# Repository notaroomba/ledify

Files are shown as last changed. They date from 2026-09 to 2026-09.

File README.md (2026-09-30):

<h1 align="center">
  <br>
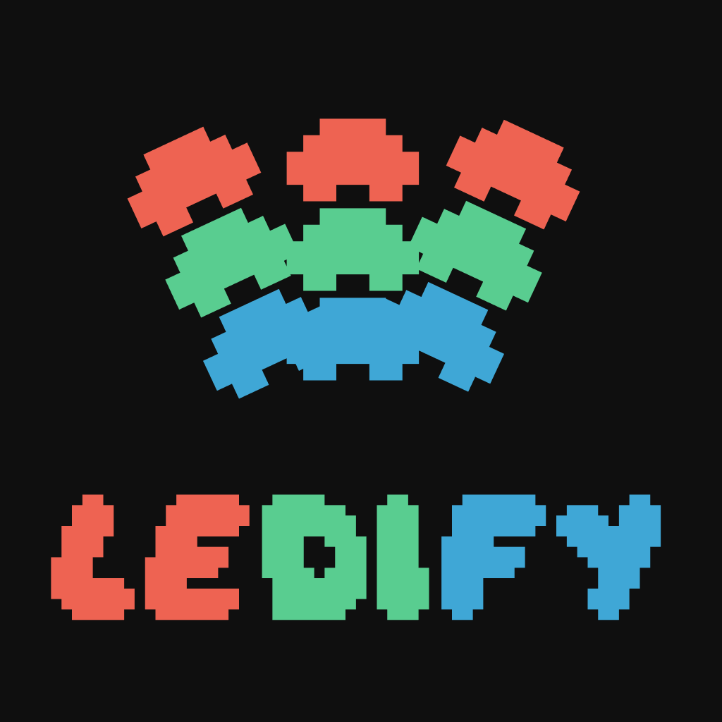
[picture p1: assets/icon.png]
Ledify
  
</h1>

<h4 align="center">
A super small addressable LED controller with USB-C PD up to 100W, a switchable 5V/12V output and Bluetooth!
</h4>

<div align="center">





</div>

<p align="center">
  <a href="#key-features">Key Features</a> •
  <a href="#pcb">PCB</a> •
  <a href="#firmware">Firmware</a> •
  <a href="#credits">Credits</a> •
  <a href="#license">License</a>
</p>

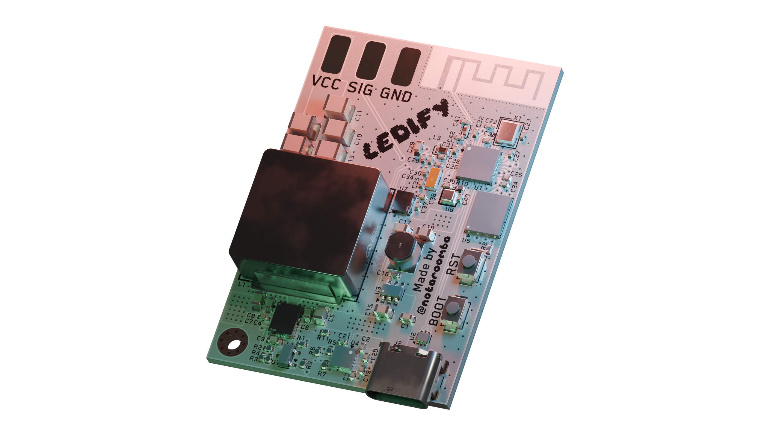
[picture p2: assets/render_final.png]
Ledify Render


## Key Features

- **ESP32-C6** microcontroller with Wi-Fi 6 and Bluetooth LE
- **16MB flash** (W25Q128JVP)
- **USB-C PD** up to 100W with the FUSB302B
- **Switchable 5V/12V LED output** from a 10A buck converter (LM61495), selected in software
- **Addressable LED pads** (VCC / SIG / GND) for WS2812B, WS2811 and WS2815 strips
- **IMU and Barometer** - BMI323 (6-axis) and BMP581 pressure sensor
- **Ambient light sensor** (OPT4001) for automatic brightness
- **I2S microphone** (ICS-43434) for sound-reactive effects
- **PCB trace antenna** with an impedance matching network
- **3.3V buck converter** (AP63203) for the logic side
- **ESD protection** on the USB data lines
- **Reset and boot buttons** and a mounting hole
- **4-layer PCB** design with optimized RF layout and routing

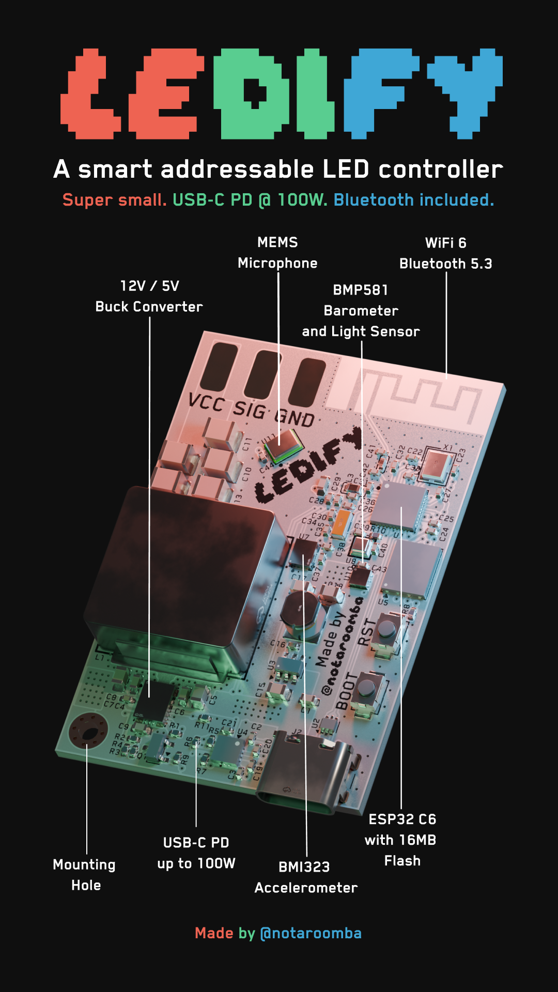
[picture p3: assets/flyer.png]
Ledify Flyer


## PCB

Designed in KiCad with attention to RF design and high current power delivery. The board is 4 layers with a solid ground plane under the ESP32, the flash and the antenna feed, and the LED buck follows the layout in the LM61495 datasheet.

### Schematic

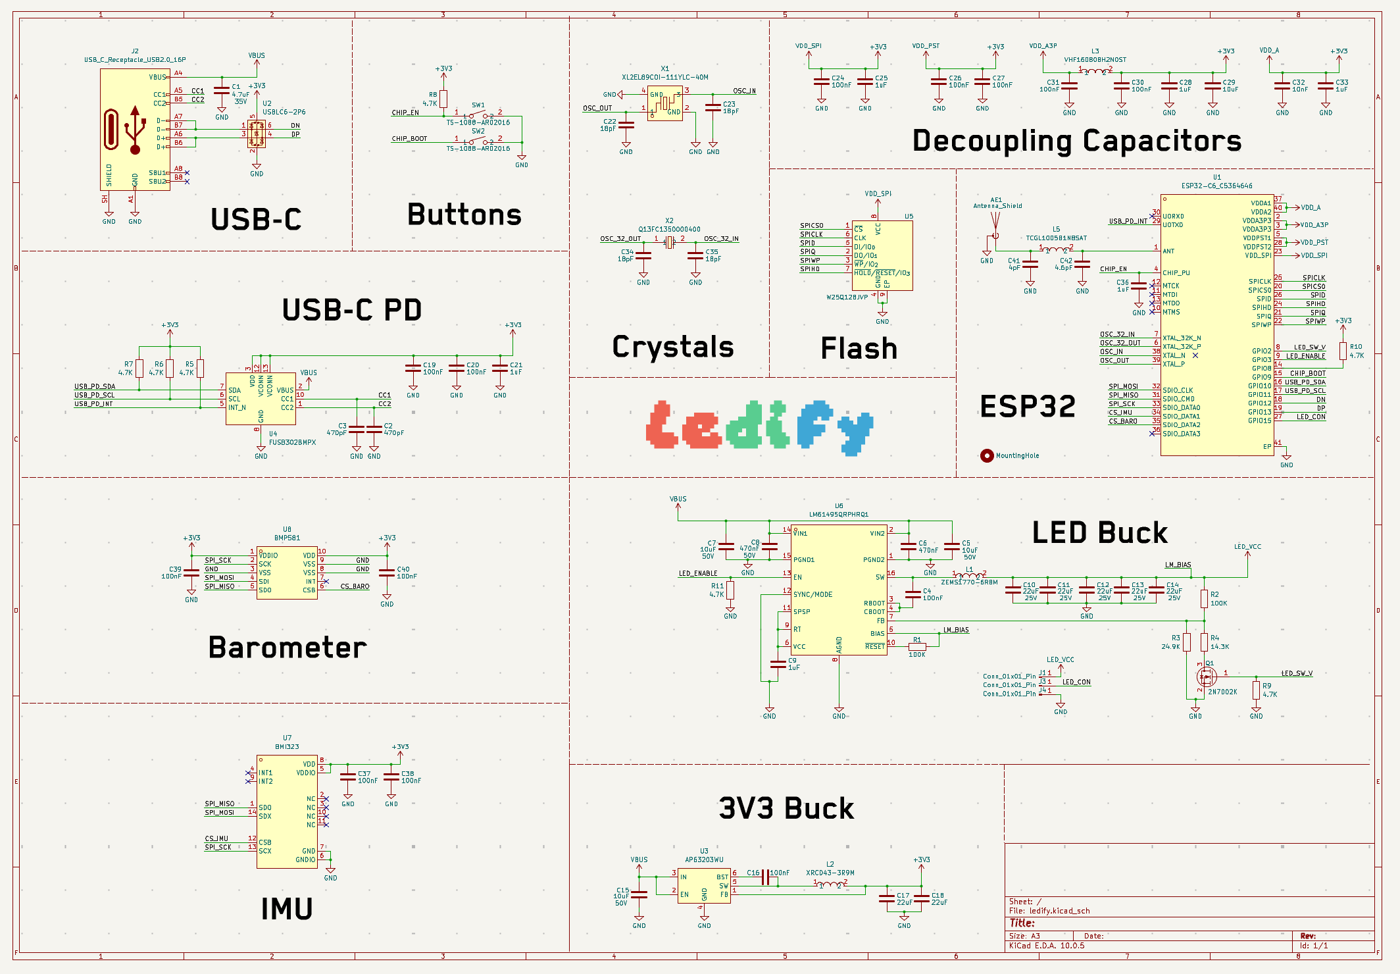
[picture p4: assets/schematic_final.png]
Schematic


### Layout

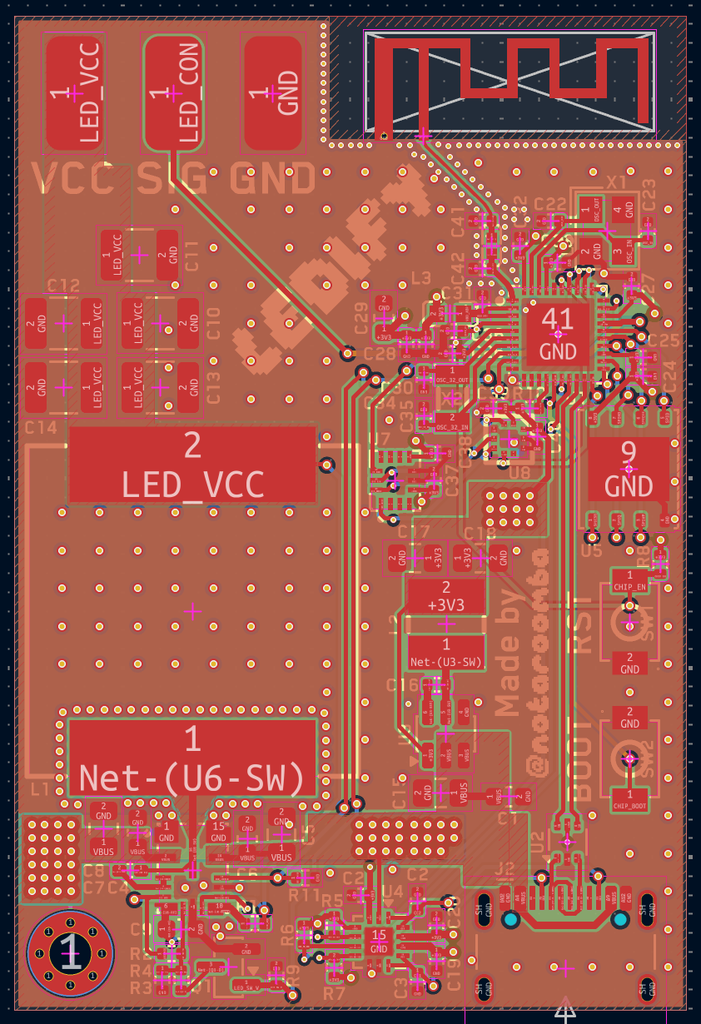
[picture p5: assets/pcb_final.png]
PCB Layout


### Pinout

| GPIO | Net | Function |
| ---- | --- | --- |
| 2 | LED_SW_V | LED voltage select (low = 5V, high = 12V) |
| 3 | LED_ENABLE | LED buck enable |
| 5 | LED_CON | LED data (SIG pad) |
| 6 | MIC_OUT | Microphone I2S data |
| 22 | MIC_CS | Microphone I2S word select |
| 23 | MIC_SCK | Microphone I2S bit clock |
| 10 | I2C_SDA | I2C data (FUSB302B, OPT4001) |
| 11 | I2C_SCL | I2C clock (FUSB302B, OPT4001) |
| 16 | USB_PD_INT | FUSB302B interrupt |
| 18 | SPI_MISO | Sensor SPI |
| 19 | SPI_MOSI | Sensor SPI |
| 20 | SPI_SCK | Sensor SPI |
| 21 | CS_IMU | BMI323 chip select |
| 7 | CS_BARO | BMP581 chip select |
| 12 | DN | USB D- |
| 13 | DP | USB D+ |
| 9 | CHIP_BOOT  | Boot button |
| 8 | - | Strapping pin, pulled up to 3V3 |

### JLCPCB Quote

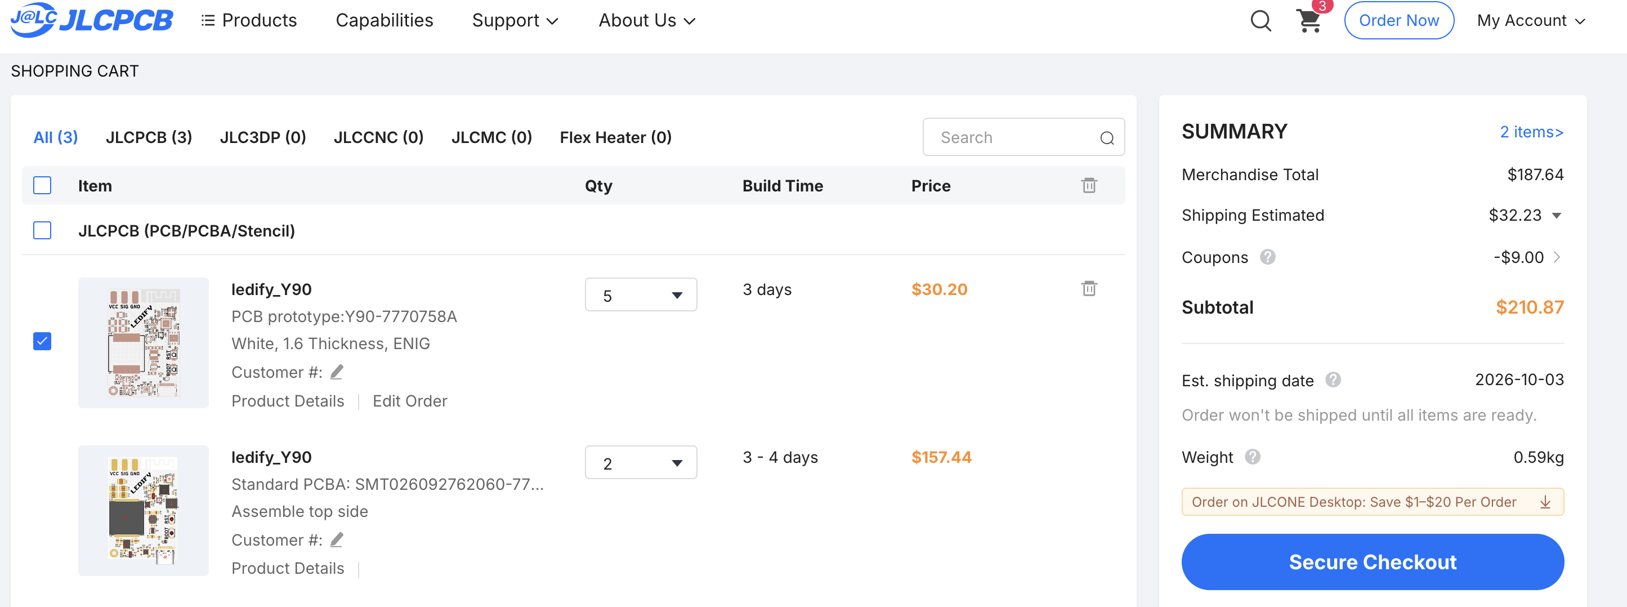
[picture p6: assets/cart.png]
JLCPCB Quote


## Firmware

The boilerplate in [`firmware/main.py`](firmware/main.py) is written in MicroPython. It advertises over Bluetooth as `Ledify` with the Nordic UART service, so any BLE UART app (nRF Connect, Bluefruit Connect) can control the strip.

| Command | Action |
| --- | --- |
| `on` | Turns on the LED buck |
| `off` | Clears the strip and turns off the LED buck |
| `rgb R G B` | Fills the strip with a color (0-255 each) |
| `volt 5` | Selects 5V, turns the output off first |
| `volt 12` | Selects 12V, turns the output off first |

The output always boots at 5V and off. Set `NUM_LEDS` and `MAX_LEVEL` at the top of the file for your strip.

### Flashing

1. Flash the [MicroPython ESP32-C6 firmware](https://micropython.org/download/ESP32_GENERIC_C6/) over USB with `esptool`
2. Copy the boilerplate to the board:

```bash
mpremote cp firmware/main.py :main.py
```

3. Press RST and connect to `Ledify` over Bluetooth

To run the parser self-check on your computer:

```bash
python3 firmware/main.py
```

## Credits

This project uses:

- [KiCad](https://www.kicad.org/)
- [Blender](https://www.blender.org/) for 3D renders
- [MicroPython](https://micropython.org/)

## You may also like...

- [Cyberboard](https://github.com/NotARoomba/cyberboard) – A Raspberry Pi Pico-sized STM32 development board
- [CyberCard](https://github.com/NotARoomba/CyberCard) – A Cyberpunk themed NFC hacker card
- [Ember](https://github.com/NotARoomba/ember) – USB-C PD Powered Hotplate
- [Trace](https://github.com/NotARoomba/trace) – An ruler for engineers
- [Athena](https://github.com/NotARoomba/athena) – A flight controlelr with a triple MCU architecture

## License

MIT

---

> [notaroomba.dev](https://notaroomba.dev) &nbsp;&middot;&nbsp;
> GitHub [@NotARoomba](https://github.com/NotARoomba) &nbsp;&middot;&nbsp;

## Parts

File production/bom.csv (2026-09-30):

Designator | Footprint | Quantity | Value | LCSC Part #
AE1 | Texas_SWRA117D_2.4GHz_Right | 1 | Antenna_Shield
C1 | 0603 | 1 | 4.7uF 35V | C307467
C10, C11, C12, C13, C14 | 1210 | 5 | 22uF 25V | C309062
C15, C5, C7 | 0805 | 3 | 10uF 50V | C440198
C16, C19, C20, C24, C26, C27, C30, C31, C37, C38, C39, C4, C40, C43, C44 | 0402 | 15 | 100nF
C17, C18 | 0805 | 2 | 22uF
C2, C3 | 0402 | 2 | 470pF | C76971
C21, C25, C28, C33, C36 | 0402 | 5 | 1uF
C22, C23, C34, C35 | 0402 | 4 | 18pF | C1549
C29 | 0603 | 1 | 10uF
C32 | 0402 | 1 | 10nF
C41 | 0402 | 1 | 4pF | C541337
C42 | 0402 | 1 | 4.6pF | C1855288
C6, C8 | 0603 | 2 | 470nF 50V | C77572
C9 | 0603 | 1 | 1uF
J1, J3, J4 | SolderWirePad_1x01_SMD_3x6mm | 3 | Conn_01x01_Pin
J2 | USB_C_Receptacle_HCTL_HC-TYPE-C-16P-01A | 1 | USB_C_Receptacle_USB2.0_16P | C2894897
L1 | IND-SMD_L17.5-W17.5_SLO1770H | 1 | ZEMS1770-6R8M | C41438687
L2 | IND-SMD_L4.0-W3.2_XRCD43 | 1 | XRCD43-3R9M | C5289397
L3 | L0603 | 1 | VHF160808H2N0ST | C395081
L5 | L0402 | 1 | TCGL1005B1N8SAT | C52109814
Q1 | SOT-23 | 1 | 2N7002K
R1, R2 | 0402 | 2 | 100K
R10, R11, R5, R6, R7, R8, R9 | 0402 | 7 | 4.7K
R3 | 0402 | 1 | 24.9K
R4 | 0402 | 1 | 14.3K | C25855
SW1, SW2 | SW-SMD_L3.9-W3.0-P4.45 | 2 | TS-1088-AR02016 | C720477
U1 | QFN-40_L5.0-W5.0-P0.40-TL-EP3.3 | 1 | ESP32-C6_C5364646 | C5364646
U10 | USON-6_L2.0-W2.0-P0.65-BL-EP | 1 | OPT4001DNPRQ1 | C20199903
U11 | MIC-SMD_6P-L3.5-W2.7-P0.90-BL | 1 | ICS-43434_C5656610 | C5656610
U2 | SOT-666 | 1 | USBLC6-2P6
U3 | TSOT-23-6 | 1 | AP63203WU | C780769
U4 | WQFN-14-1EP_2.5x2.5mm_P0.5mm_EP1.45x1.45mm | 1 | FUSB302BMPX | C132291
U5 | WSON-8-1EP_6x5mm_P1.27mm_EP3.4x4.3mm | 1 | W25Q128JVP | C2441427
U6 | VQFN-16_L4.5-W3.5-P0.50-TL_TI_RPH | 1 | LM61495QRPHRQ1 | C3188410
U7 | LGA-14_L3.0-W2.5-P0.50-TL_QMI8658A | 1 | BMI323 | C5368700
U8 | LGA-10_L2.0-W2.0-P0.50-TL_BMP581 | 1 | BMP581 | C5362283
X1 | CRYSTAL-SMD_4P-L3.2-W2.5-BL | 1 | XL2EL89COI-111YLC-40M | C18214314
X2 | FC-135R_L3.2-W1.5 | 1 | Q13FC1350000400 | C32346

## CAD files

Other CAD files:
blender/ledify.blend

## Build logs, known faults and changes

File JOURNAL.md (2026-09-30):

# Sep 5, 2026

So I'm doing a thing where I'm trying to make a simple led controller that works with USB-C PD and yea. I want this to be able to power either 12V or 5V LEDs depending on a switch in software and ya. I got this so far as I'm using the FUSB302BMPX for USB-C PD negotiation and yea. I still have to choose my buck converters.

Finished big buck and also small buck and learned about n channel and p channel mosfets.
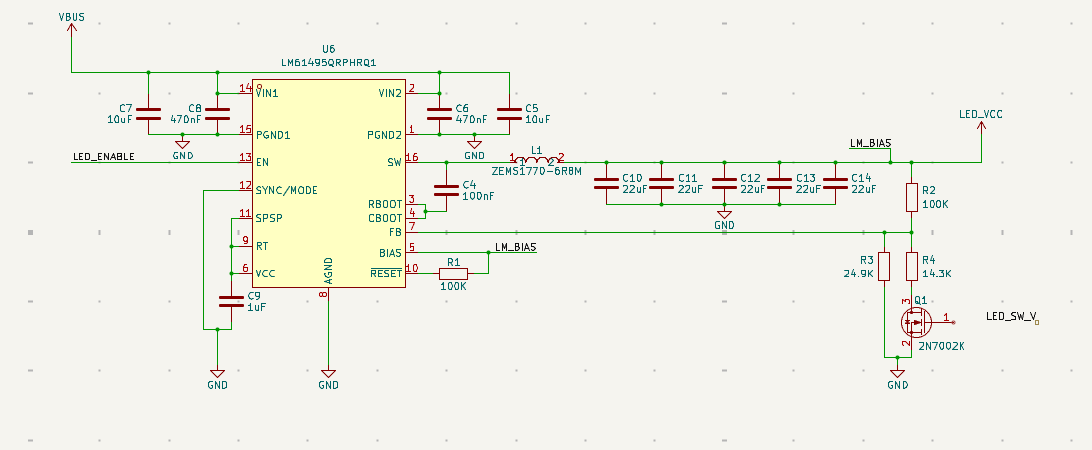
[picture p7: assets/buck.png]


**Total time spent: 6 hours**

# Sep 12, 2026

got basically everything done except the esp32 itself

so I have the usb c going into the FUSB302 for the PD stuff over i2c and then a USBLC6 for esd on the data lines. then theres the small buck (AP63203) that makes the 3V3 for the esp and the big buck with the HUGE inductor for the leds and yea I have the mosfet thing on the feedback so I can switch 5V or 12V from software

also added the crystal and all the decoupling caps for the esp, theres like a million power pins on the c6 (VDDA, VDDA3P3, VDDPST, VDD_SPI) so I put a ferrite on the analog one and caps on all of them like the datasheet says

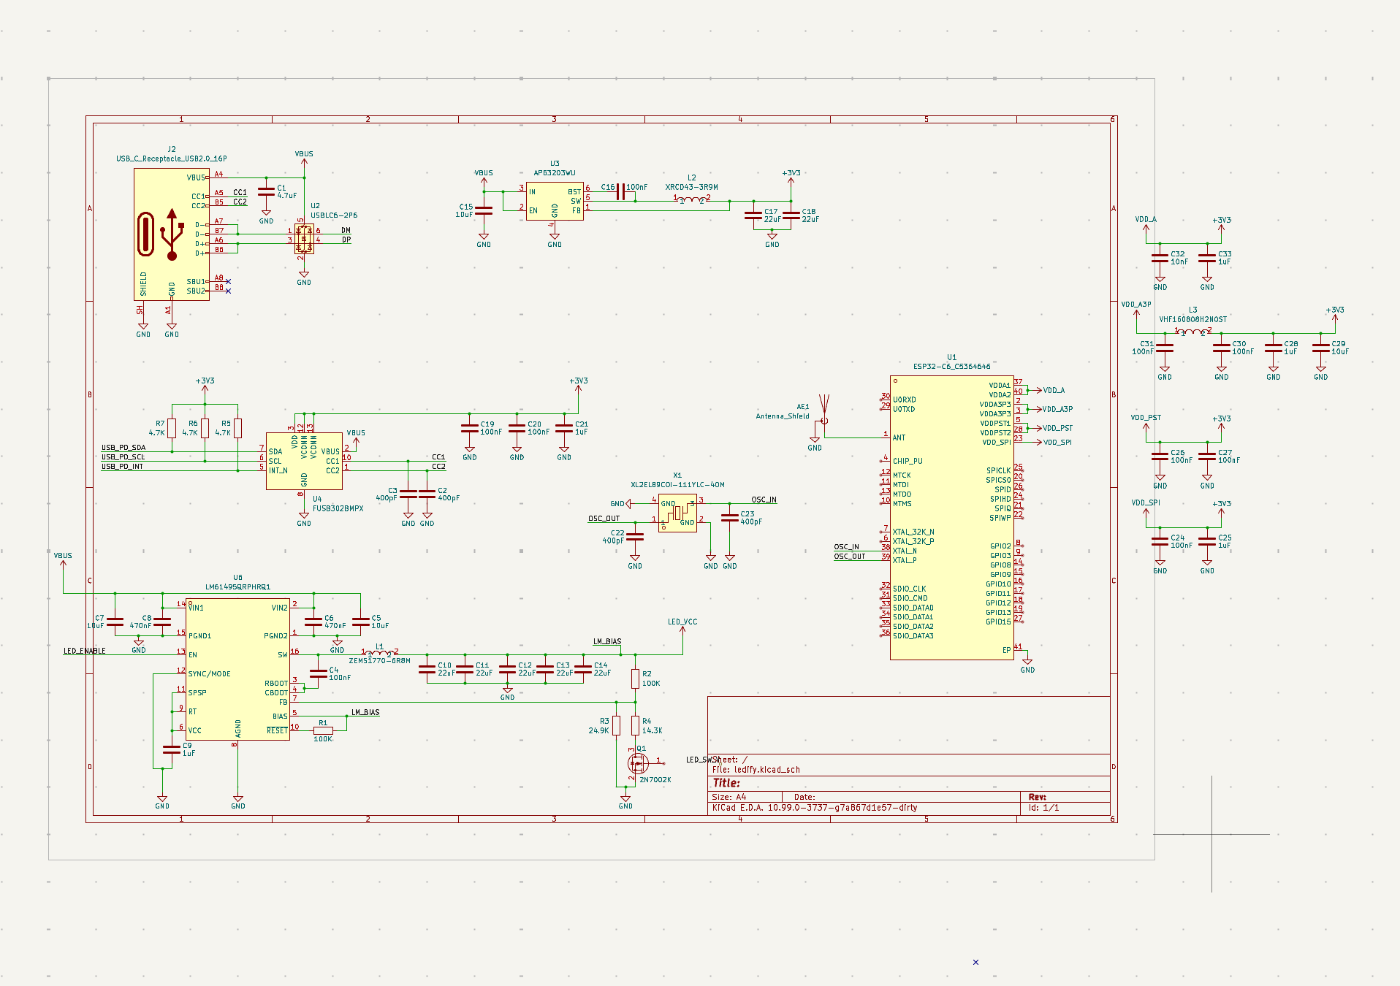
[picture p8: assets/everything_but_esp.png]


now I just have to figure out the esp pinout because I have no idea what goes where lol

**Total time spent: 7 hours**

# Sep 13, 2026

ookay so I've been working on this on and off whenever I had time and I finally got around to finishing the schematic

the thing was I didn't know the esp32 pinout at all so I went through the datasheet and looked at some example schematics that other people made to get an idea of what goes where

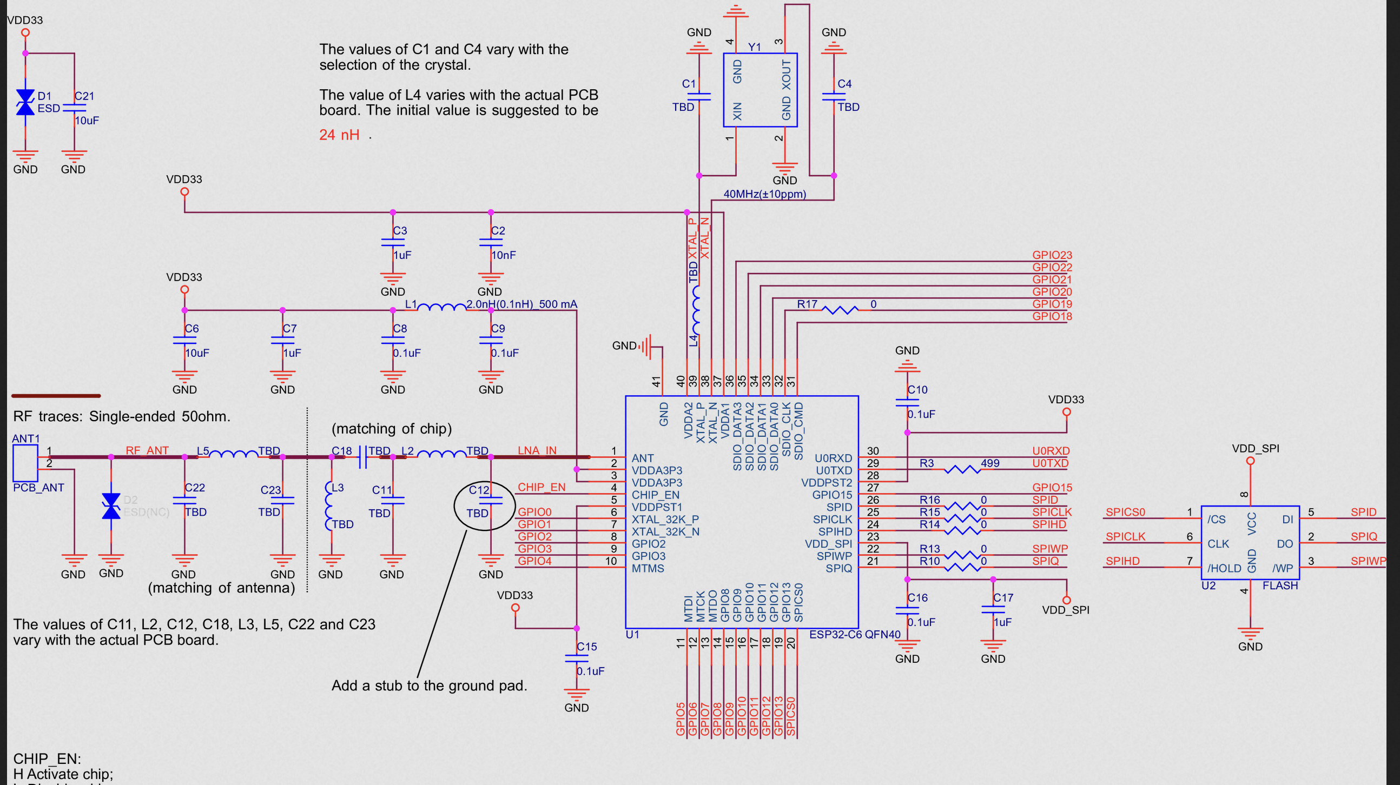
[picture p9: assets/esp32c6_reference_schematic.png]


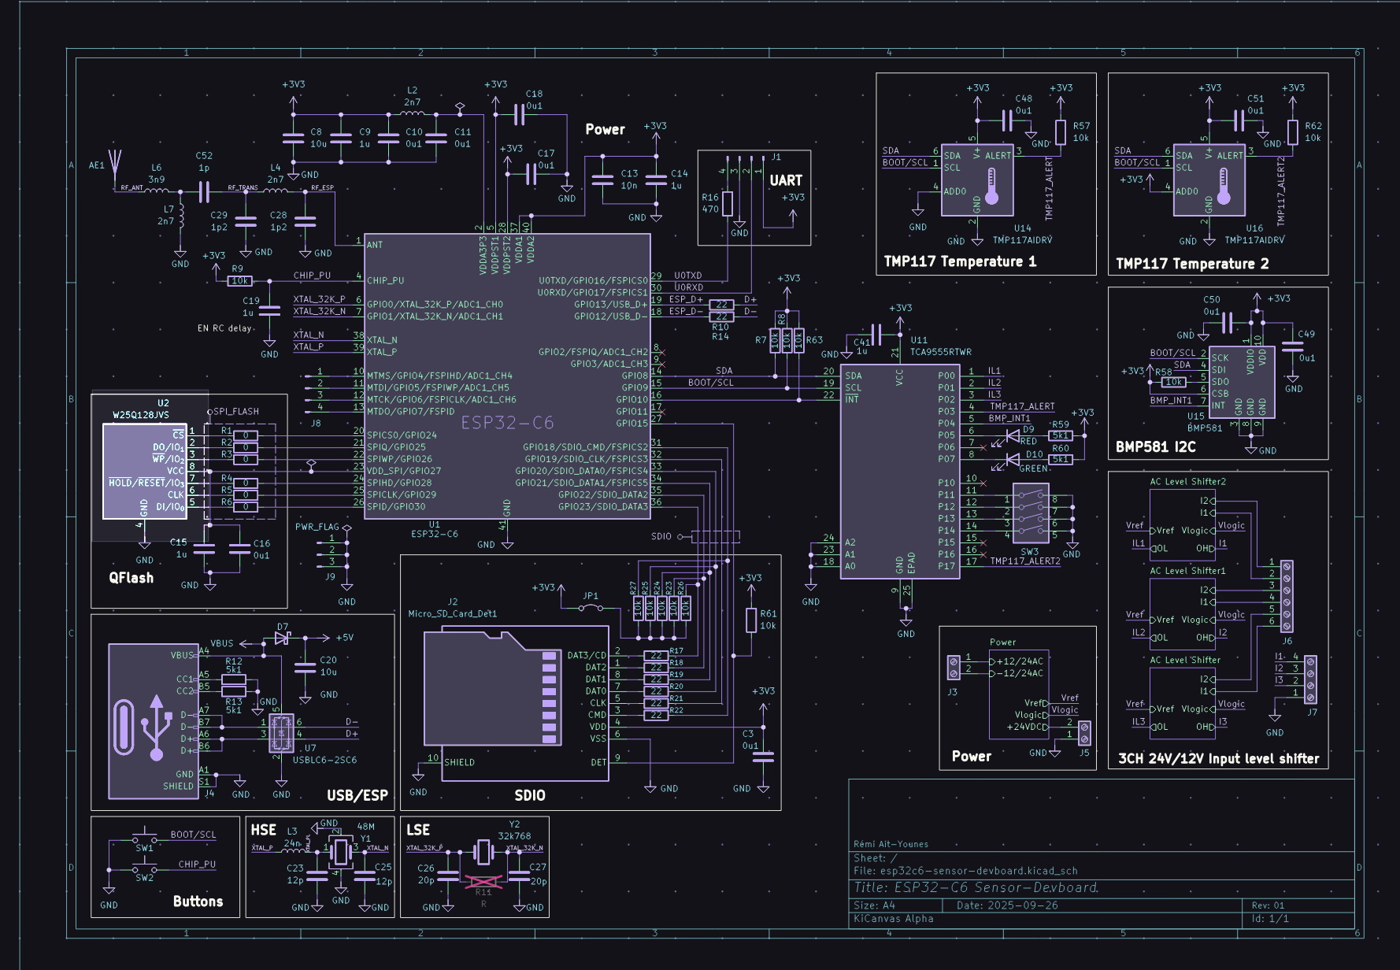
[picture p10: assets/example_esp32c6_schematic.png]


and thats when I found out that on the esp32 literally ANY gpio can be spi or i2c because of the gpio matrix (with some regulations lol) so like you cant use 24-30 because thats the flash on the 40 pin version and 12/13 are usb and 8/9/15 are strapping pins so nothing can pull them at boot. also there are no input only pins on the c6 unlike the og esp32 so that made it easier and yea

**Total time spent: 6 hours**

# Sep 19, 2026

after that I had to go back and look at the datasheet for the big buck again because I wanted to make sure the 5V/12V thing actually worked. basically theres a voltage divider on the feedback pin and the 2N7002K puts another resistor in parallel with the bottom one so off = 5V and on = 12V

but then I realized that when the esp is booting the gpio floats so the mosfet could randomly turn on and send 12V to a 5V strip and kill it so I decided to put a pull down resistor on the gate so it defaults to 5V

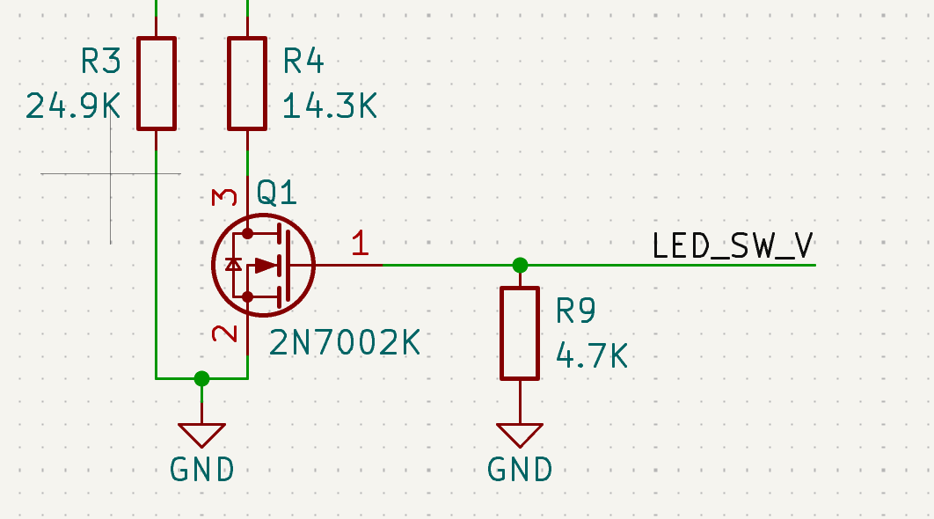
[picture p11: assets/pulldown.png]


also had to double check all the caps because VBUS can go up to 20V with PD so the input caps need to be rated for way more than what I had

**Total time spent: 6 hours**

# Sep 20, 2026

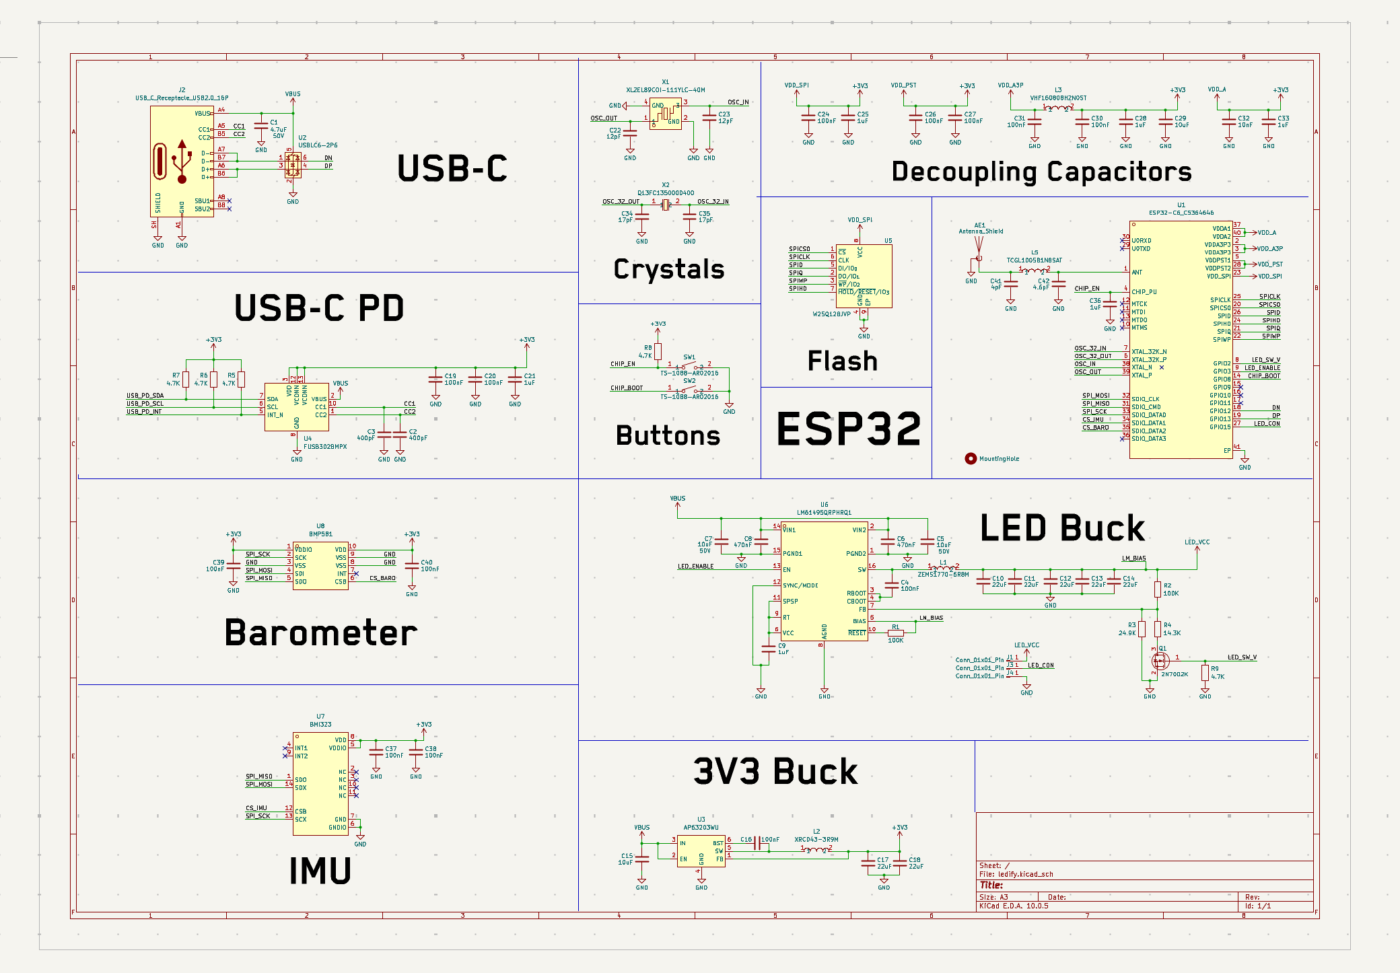
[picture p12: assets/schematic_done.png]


schematic done so now its time for the pcb!!!

I had some trouble laying it out at first because the led inductor is HUGE (17.5mm) and I didn't know where to put it next to the esp and the flash. turns out its fine to have it next to the flash as long as the switch node is pointing away and the ground plane is solid so I just rotated it

the bigger problem was the antenna, I originally had it in the top left with the led pads and the crystal right next to it. so I moved the antenna to the top right corner against both edges and the led pads to the other side and the crystal below the esp

after a bit of moving stuff around I finally decided on a general layout and grouped everything (usb, small buck, big buck, esp + flash) and started routing

**Total time spent: 5 hours**

# Sep 26, 2026

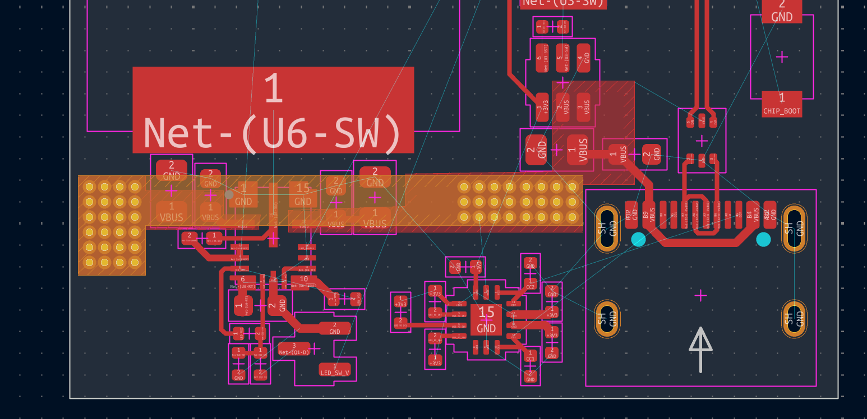
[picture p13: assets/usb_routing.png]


I routed the usb stuff first since that was the easiest and then went through the rest

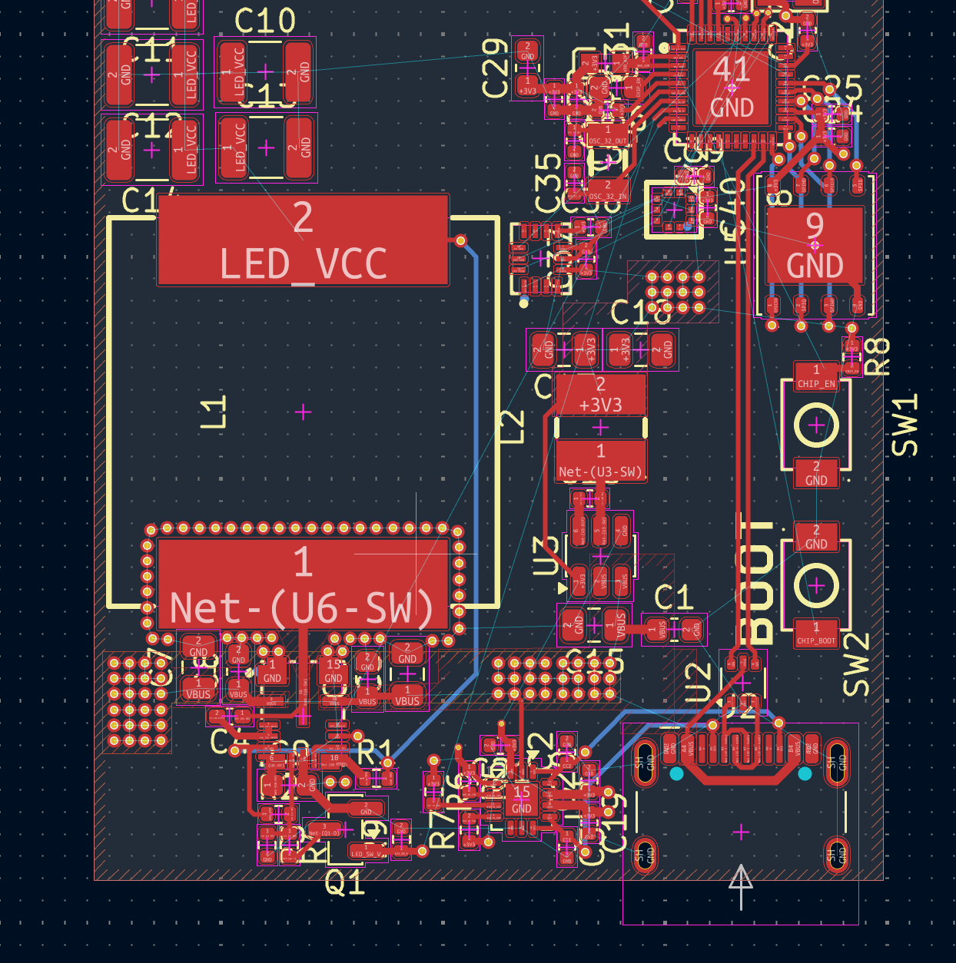
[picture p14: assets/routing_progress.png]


then it was time for the antenna and heres where I had to learn a bit more about rf theory. I'm using a meander pcb antenna and apparently the ground plane is literally part of the antenna so it has to be at a specific distance from it. I originally had a massive keepout below it with the feed trace running through empty board which is bad because the trace has no ground reference so its basically another antenna lol

so I pulled the ground pour up so its right under the antenna pads and made the feed trace super short with vias on both sides and yea

I also had to make a matching circuit for the first time!! the esp is like 35 + 10j ohms and the antenna wants 50 + 0j so I had to calculate the pi network to get it there and it was the first time actually doing the smith chart stuff for real instead of just copying values

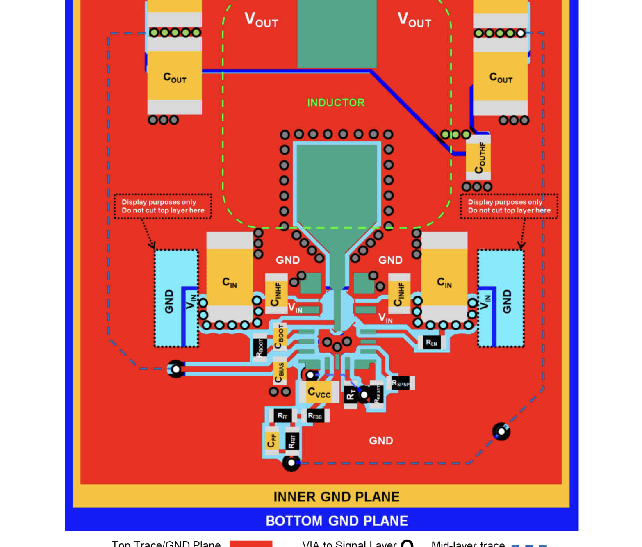
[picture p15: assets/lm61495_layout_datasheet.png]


for the big buck I followed the layout in the datasheet and kept the input caps right at the pins since thats the hot loop. I was also wondering if I should mirror the LED_VCC pour on the bottom with vias for the current but it would cut a hole in the ground plane so I left the ground plane alone

and after around 7 hours of routing today its DONE

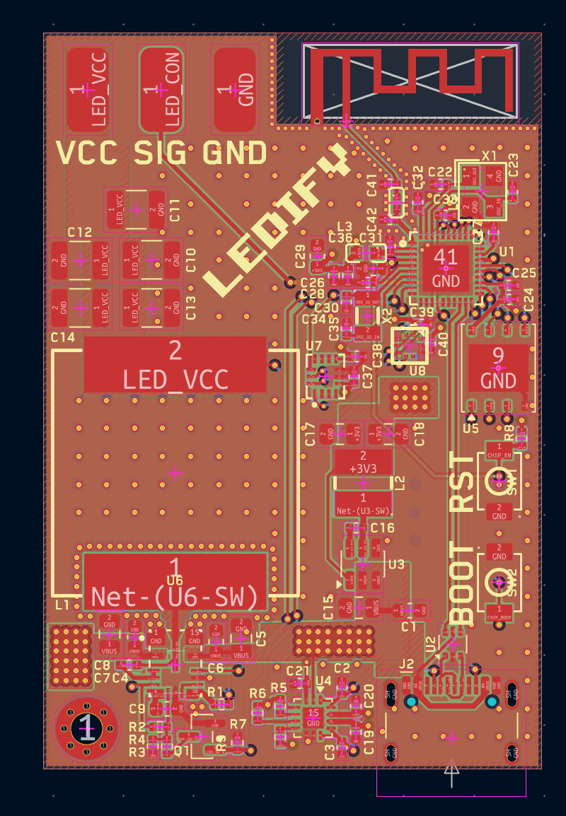
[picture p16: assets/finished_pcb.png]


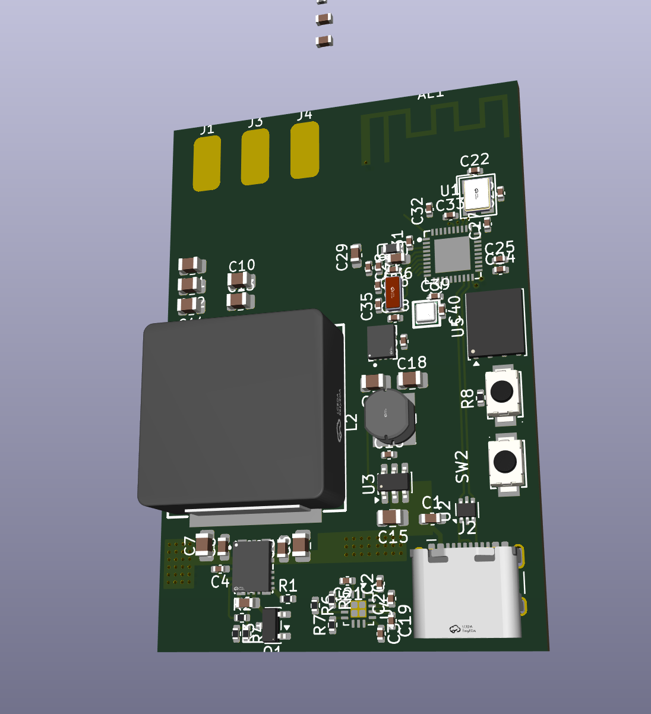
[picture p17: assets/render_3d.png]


**Total time spent: 8 hours**

# Sep 27, 2026

I then did a think with LCSC and JLCPCB and got the final quote on it, I had to bom match because of the 22uF caps adn they had to be rated for 25V because yea usb goes up to 20v


In total it went up to 210 usd ish with shipping and assembly so I think that this is good.

**Total time spent: 2.5 hours**

# Sep 28, 2026

ookay so with the pcb done I started on the blender render yesterday and yea

I exported the board as a pcb3d and imported it into blender and then set up the camera and a bunch of lights around it

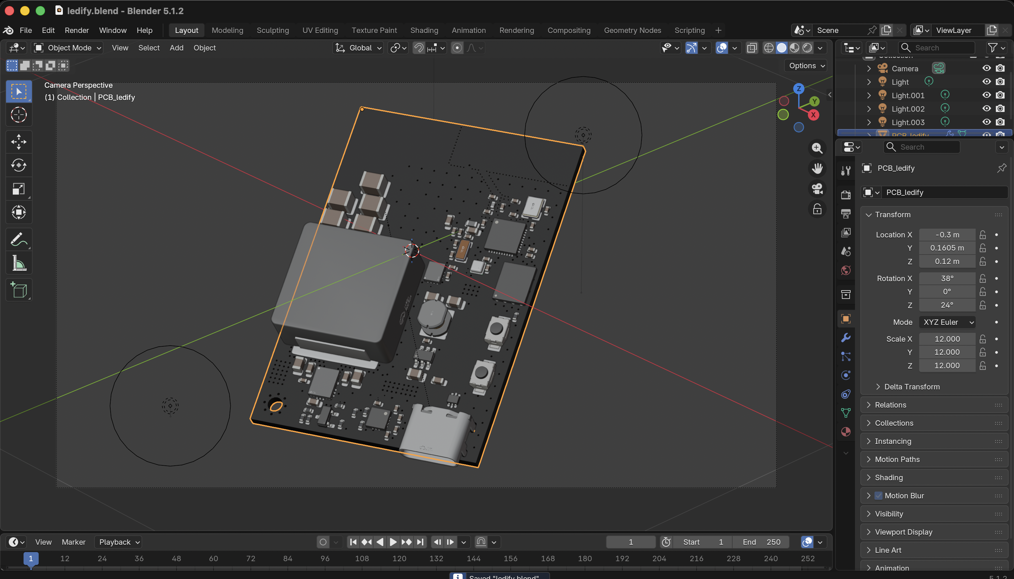
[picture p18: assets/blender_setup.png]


the first renders looked kinda drab so I went through a few versions moving the lights around and giving them colors (red green and blue like an rgb led lol) until it looked good

then today I went on figma and made the logo and the banner and also a flyer that shows everything on the board. I also found a cool pixel font for the name and put it on the silkscreen too

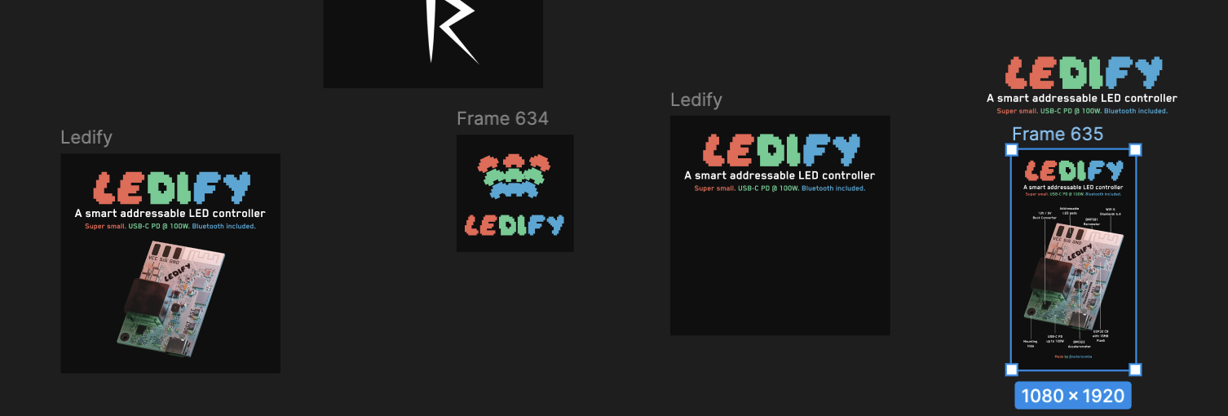
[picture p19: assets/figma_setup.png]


and this is how it ended up!!

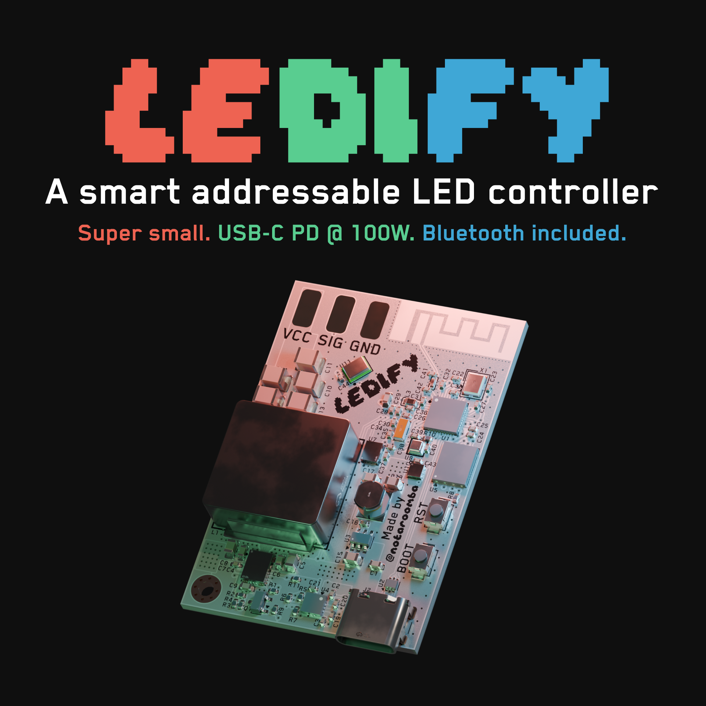
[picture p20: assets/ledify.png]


but then I went back and double checked the schematic and found a few errors lol

the biggest one was that the FUSB302 i2c lines weren't even connected to the esp (they just went to the pull up resistors) so it wouldn't have been able to get anything above 5V which is kinda the whole point of the board. I also had the boot button on GPIO8 instead of GPIO9 so I moved it and put a pull up on GPIO8

then theres the usb esd chip, I had its VBUS pin on VBUS but it can only handle like 6V so with PD at 20V it would have died, so now its on 3V3. I also added a pull down on the led enable so the buck doesn't turn on by itself when the esp is booting

after that I went through all of the LCSC part numbers and some of them didn't match, like the 10uF caps on VBUS were actually 25V instead of 50V and the crystal caps were wrong (the crystals want a 12pF load so the caps have to be 18pF) so I fixed those too





and now the drc has no more errors and the bom matches the schematic so its finally ready to order

**Total time spent: 5 hours**

# Sep 29, 2026

so the board was "done" but I kept thinking of stuff to add lol

first I wanted an ambient light sensor so the leds can dim themselves when the room is dark. I went with the OPT4001 and it's i2c so I just put it on the same bus as the FUSB302 and didn't have to use any more pins. the only space left was next to the 3V3 buck so I put it on the output side away from the inductor. when I added it I accidentally ran some tracks straight through a group of 3V3 vias and shorted CHIP_EN and MISO to 3V3 so I had to fix that

then I looked at the return paths around the esp32 because I thought it was interesting and it turns out I had signal tracks on the inner layers cutting slots in the ground plane right under the chip, and there was only ONE ground via under the esp. so I moved CS_BARO and LED_CON off the planes, changed a few pins around (led data is on GPIO5 now and CS_BARO on GPIO7) and added more ground vias under it

after that I wanted a microphone so the leds can react to sound. I started with an analog one (ZTS6117) but the output is only a few millivolts so the esp adc can't really read it without an op amp and like 10 more parts. so I looked at the MAX9814 and then decided on an i2s mic instead because its one part and the signal is digital so the bucks can't mess with it
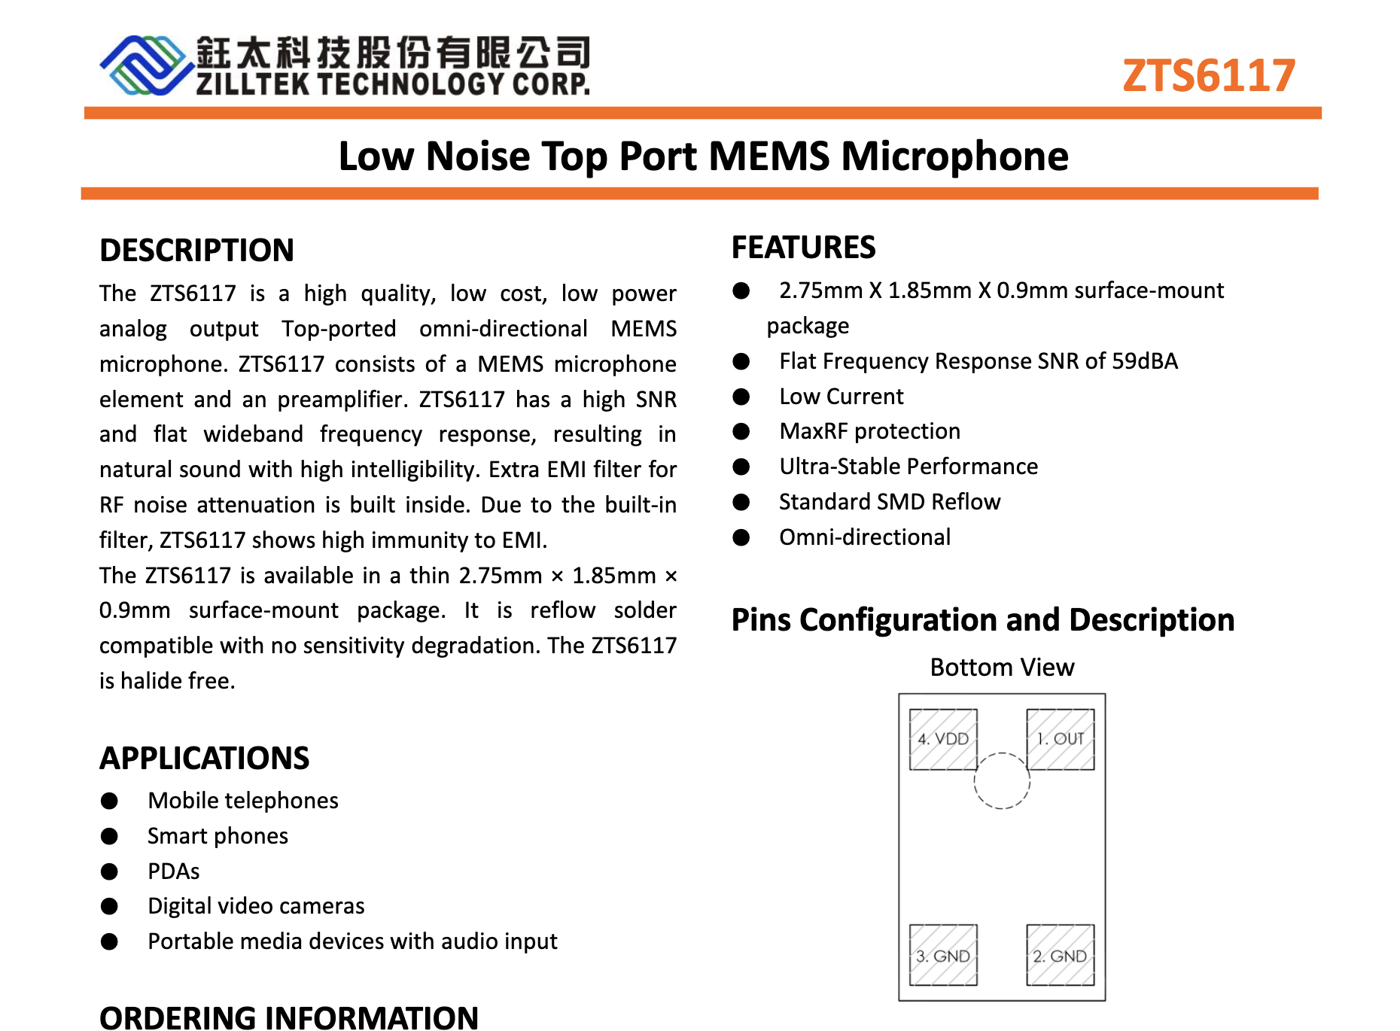
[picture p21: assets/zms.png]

I also tied SYNC/MODE on the big buck to 3V3 so it always switches at the same frequency and doesn't make the caps hum next to the mic

**Total time spent: 4 hours**

# Sep 30, 2026

the i2s mic I picked (MSM261S4030H0R) was out of stock on LCSC so I spent a while looking for another one. apparently top port i2s mics basically don't exist, almost all of them have the hole on the bottom, so I went with the ICS-43434 which is a bit smaller and listens through a hole in the pcb

the footprint had the sound hole as a plated hole with no copper around it which jlc can't make so I changed it to a 0.5mm non plated hole

I also double checked the antenna again. the feed trace is the 50 ohm width for the JLC04161H-3313 stackup and nothing is inside the keepout on any layer so I just have to remember to pick that stackup when I order

then I fixed a 0.1mm track I missed, exported the production files again and redid the renders with the new parts



with the extra sensors the pcba is around 300 usd now for 2 assembled boards, I looked at how much it would be to assemble them myself and its way cheaper per board but the esp32 is 0.4mm pitch and there are 3 LGA sensors so I'm going with pcba for this one

**Total time spent: 2.5 hours**

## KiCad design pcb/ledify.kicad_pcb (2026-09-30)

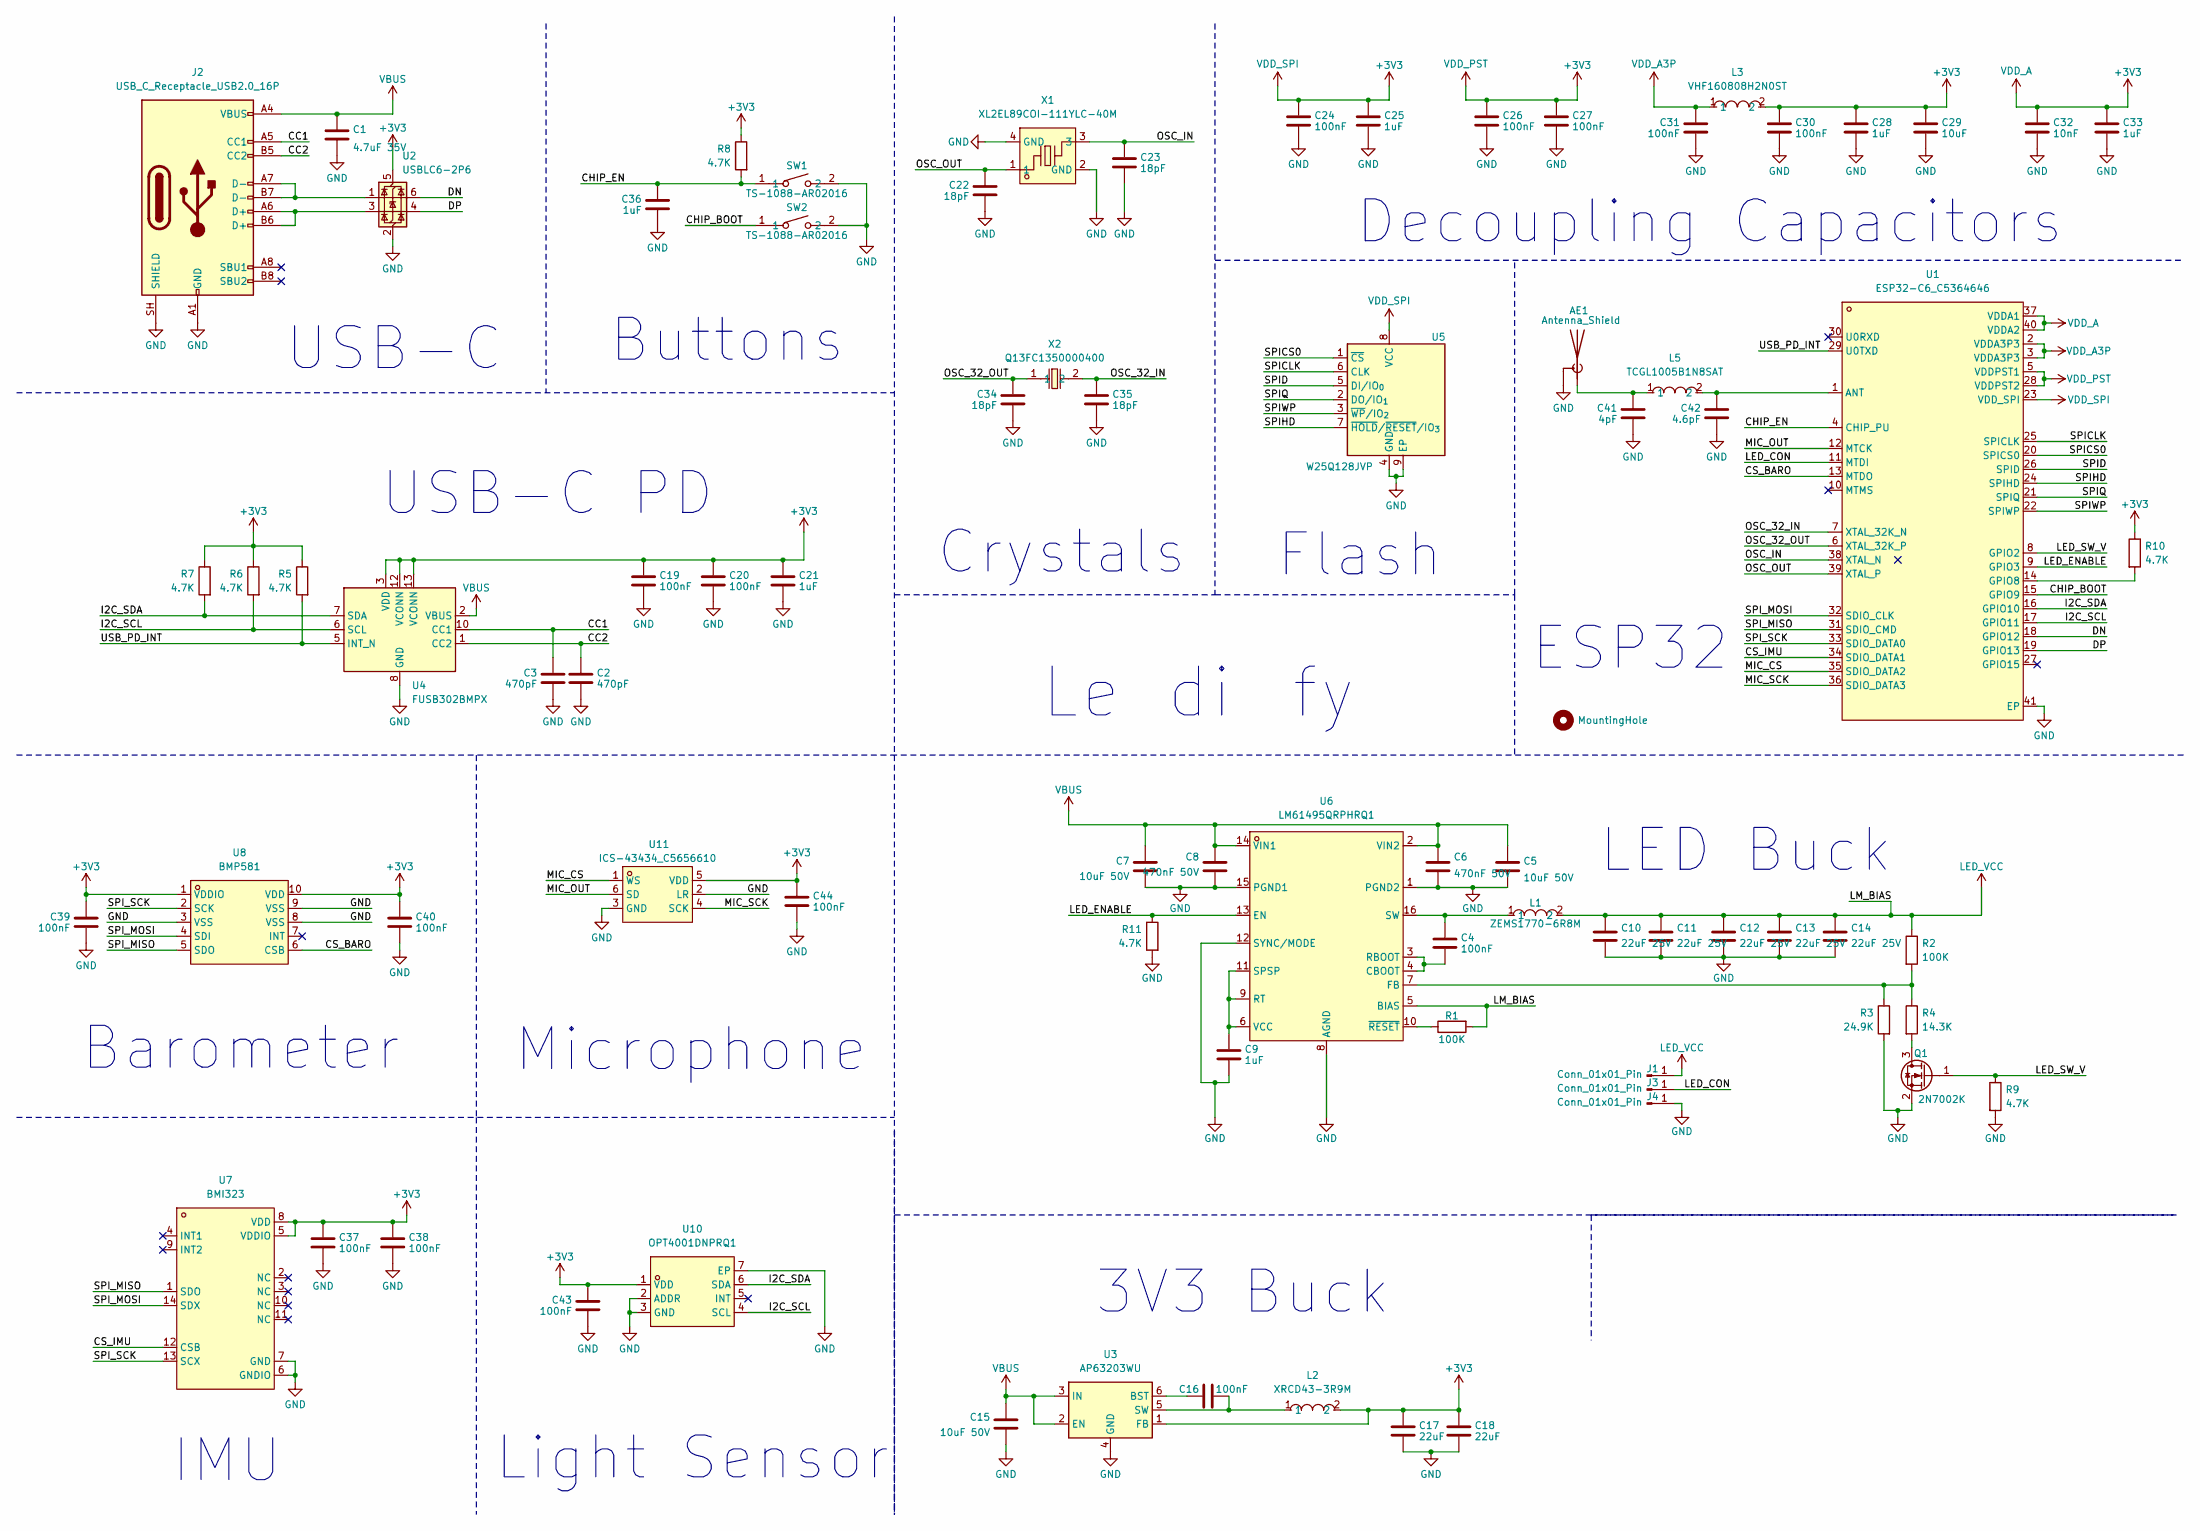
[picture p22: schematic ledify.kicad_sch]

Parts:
AE1: Antenna_Shield; Texas_SWRA117D_2.4GHz_Right
C1: 4.7uF 35V; C_0603_1608Metric; LCSC C307467
C2, C3: 470pF; C_0402_1005Metric; LCSC C76971
C4: 100nF; C_0402_1005Metric_Pad0.74x0.62mm_HandSolder
C5, C7, C15: 10uF 50V; C_0805_2012Metric; LCSC C440198
C6, C8: 470nF 50V; C_0603_1608Metric; LCSC C77572
C9: 1uF; C_0603_1608Metric
C10, C11, C12, C13, C14: 22uF 25V; C_1210_3225Metric; LCSC C309062
C16, C19, C20, C24, C26, C27, C30, C31, C37, C38, C39, C40, C43, C44: 100nF; C_0402_1005Metric
C17, C18: 22uF; C_0805_2012Metric
C21, C25, C28, C33, C36: 1uF; C_0402_1005Metric
C22, C23, C34, C35: 18pF; C_0402_1005Metric; LCSC C1549
C29: 10uF; C_0603_1608Metric
C32: 10nF; C_0402_1005Metric
C41: 4pF; C_0402_1005Metric; LCSC C541337
C42: 4.6pF; C_0402_1005Metric; LCSC C1855288
H1: MountingHole; MountingHole_2.2mm_M2_Pad_Via
J1, J3, J4: Conn_01x01_Pin; SolderWirePad_1x01_SMD_3x6mm
J2: USB_C_Receptacle_USB2.0_16P; USB_C_Receptacle_HCTL_HC-TYPE-C-16P-01A; LCSC C2894897
L1: ZEMS1770-6R8M; IND-SMD_L17.5-W17.5_SLO1770H; MPN ZEMS1770-6R8M; LCSC Part C41438687
L2: XRCD43-3R9M; IND-SMD_L4.0-W3.2_XRCD43; MPN XRCD43-3R9M; LCSC Part C5289397
L3: VHF160808H2N0ST; L0603; MPN VHF160808H2N0ST; LCSC Part C395081
L5: TCGL1005B1N8SAT; L0402; MPN TCGL1005B1N8SAT; LCSC Part C52109814
Q1: 2N7002K; SOT-23
R1, R2: 100K; R_0402_1005Metric
R3: 24.9K; R_0402_1005Metric
R4: 14.3K; R_0402_1005Metric; LCSC C25855
R5, R6, R7, R8, R9, R10, R11: 4.7K; R_0402_1005Metric
SW1, SW2: TS-1088-AR02016; SW-SMD_L3.9-W3.0-P4.45; MPN TS-1088-AR02016; LCSC Part C720477
U1: ESP32-C6_C5364646; QFN-40_L5.0-W5.0-P0.40-TL-EP3.3; MPN ESP32-C6; LCSC Part C5364646
U2: USBLC6-2P6; SOT-666
U3: AP63203WU; TSOT-23-6; LCSC C780769
U4: FUSB302BMPX; WQFN-14-1EP_2.5x2.5mm_P0.5mm_EP1.45x1.45mm; LCSC C132291
U5: W25Q128JVP; WSON-8-1EP_6x5mm_P1.27mm_EP3.4x4.3mm; LCSC C2441427
U6: LM61495QRPHRQ1; VQFN-16_L4.5-W3.5-P0.50-TL_TI_RPH; MPN LM61495QRPHRQ1; LCSC Part C3188410
U7: BMI323; LGA-14_L3.0-W2.5-P0.50-TL_QMI8658A; MPN BMI323; LCSC Part C5368700
U8: BMP581; LGA-10_L2.0-W2.0-P0.50-TL_BMP581; MPN BMP581; LCSC Part C5362283
U10: OPT4001DNPRQ1; USON-6_L2.0-W2.0-P0.65-BL-EP; MPN OPT4001DNPRQ1; LCSC Part C20199903
U11: ICS-43434_C5656610; MIC-SMD_6P-L3.5-W2.7-P0.90-BL; MPN ICS-43434; LCSC Part C5656610
X1: XL2EL89COI-111YLC-40M; CRYSTAL-SMD_4P-L3.2-W2.5-BL; MPN XL2EL89COI-111YLC-40M; LCSC Part C18214314
X2: Q13FC1350000400; FC-135R_L3.2-W1.5; MPN Q13FC13500004; LCSC Part C32346

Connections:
+3V3: C17.1, C18.1, C19.1, C20.1, C21.1, C24.1, C25.1, C26.1, C27.1, C28.1, C29.1, C30.1, C32.1, C33.1, C37.1, C38.1, C39.1, C40.1, C43.1, C44.1, L2.2, L3.2, R5.1, R6.1, R7.1, R8.1, R10.1, U1.5 (VDDPST1), U1.23 (VDD_SPI), U1.28 (VDDPST2), U1.37 (VDDA1), U1.40 (VDDA2), U2.5 (VBUS), U3.1 (FB), U4.3 (VDD), U4.4 (VDD), U4.12 (VCONN), U4.13 (VCONN), U5.8 (VCC), U7.5 (VDDIO), U7.8 (VDD), U8.1 (VDDIO), U8.10 (VDD), U10.1 (VDD), U11.5 (VDD)
/CC1: C3.1, J2.A5 (CC1), U4.10 (CC1), U4.11 (CC1)
/CC2: C2.1, J2.B5 (CC2), U4.1 (CC2), U4.14 (CC2)
/CHIP_BOOT: SW2.1, U1.15 (GPIO9)
/CHIP_EN: C36.1, R8.2, SW1.1, U1.4 (CHIP_PU)
/CS_BARO: U1.13 (MTDO), U8.6 (CSB)
/CS_IMU: U1.34 (SDIO_DATA1), U7.12 (CSB)
/DN: U1.18 (GPIO12), U2.6 (I/O1)
/DP: U1.19 (GPIO13), U2.4 (I/O2)
/I2C_SCL: R6.2, U1.17 (GPIO11), U4.6 (SCL), U10.4 (SCL)
/I2C_SDA: R7.2, U1.16 (GPIO10), U4.7 (SDA), U10.6 (SDA)
/LED_CON: J3.1 (Pin_1_1), U1.11 (MTDI)
/LED_ENABLE: R11.1, U1.9 (GPIO3), U6.13 (EN)
/LED_SW_V: Q1.1 (G), R9.1, U1.8 (GPIO2)
/MIC_CS: U1.35 (SDIO_DATA2), U11.1 (WS)
/MIC_OUT: U1.12 (MTCK), U11.6 (SD)
/MIC_SCK: U1.36 (SDIO_DATA3), U11.4 (SCK)
/OSC_32_IN: C35.1, U1.7 (XTAL_32K_N), X2.2
/OSC_32_OUT: C34.1, U1.6 (XTAL_32K_P), X2.1
/OSC_IN: C23.1, U1.38 (XTAL_N), X1.3
/OSC_OUT: C22.1, U1.39 (XTAL_P), X1.1
/SPICLK: U1.25 (SPICLK), U5.6 (CLK)
/SPICS0: U1.20 (SPICS0), U5.1 (~CS)
/SPID: U1.26 (SPID), U5.5 (DI/IO_{0})
/SPIHD: U1.24 (SPIHD), U5.7 (~HOLD/~RESET/IO_{3})
/SPIQ: U1.21 (SPIQ), U5.2 (DO/IO_{1})
/SPIWP: U1.22 (SPIWP), U5.3 (~WP/IO_{2})
/SPI_MISO: U1.31 (SDIO_CMD), U7.1 (SDO), U8.5 (SDO)
/SPI_MOSI: U1.32 (SDIO_CLK), U7.14 (SDX), U8.4 (SDI)
/SPI_SCK: U1.33 (SDIO_DATA0), U7.13 (SCX), U8.2 (SCK)
/USB_PD_INT: R5.2, U1.29 (U0TXD), U4.5 (INT_N)
GND: AE1.2 (Shield), C1.2, C2.2, C3.2, C5.2, C6.2, C7.2, C8.2, C9.2, C10.2, C11.2, C12.2, C13.2, C14.2, C15.2, C17.2, C18.2, C19.2, C20.2, C21.2, C22.2, C23.2, C24.2, C25.2, C26.2, C27.2, C28.2, C29.2, C30.2, C31.2, C32.2, C33.2, C34.2, C35.2, C36.2, C37.2, C38.2, C39.2, C40.2, C41.2, C42.2, C43.2, C44.2, J2.A1 (GND), J2.A12 (GND), J2.B1 (GND), J2.B12 (GND), J2.SH (SHIELD), J4.1 (Pin_1_1), Q1.2 (S), R3.2, R9.2, R11.2, SW1.2, SW2.2, U1.41 (EP), U2.2 (GND), U3.4 (GND), U4.8 (GND), U4.9 (GND), U4.15 (GND), U5.4 (GND), U5.9 (EP), U6.1 (PGND2), U6.8 (AGND), U6.12 (SYNC/MODE), U6.15 (PGND1), U7.6 (GNDIO), U7.7 (GND), U8.3 (VSS), U8.8 (VSS), U8.9 (VSS), U10.2 (ADDR), U10.3 (GND), U10.7 (EP), U11.2 (LR), U11.3 (GND), X1.2 (GND), X1.4 (GND)
LED_VCC: C10.1, C11.1, C12.1, C13.1, C14.1, J1.1 (Pin_1_1), L1.2, R1.2, R2.1, U6.5 (BIAS)
unnamed: AE1.1 (A), C41.1, L5.1
unnamed: J2.A6 (D+), J2.B6 (D+), U2.3 (I/O2)
unnamed: J2.A7 (D-), J2.B7 (D-), U2.1 (I/O1)
unnamed: Q1.3 (D), R4.2
unnamed: C42.1, L5.2, U1.1 (ANT)
unnamed: R10.2, U1.14 (GPIO8)
unnamed: C16.1, U3.6 (BST)
unnamed: C16.2, L2.1, U3.5 (SW)
unnamed: C4.2, U6.3 (RBOOT), U6.4 (CBOOT)
unnamed: R2.2, R3.1, R4.1, U6.7 (FB)
unnamed: C9.1, U6.6 (VCC), U6.9 (RT), U6.11 (SPSP)
unnamed: C4.1, L1.1, U6.16 (SW)
unnamed: R1.1, U6.10 (~RESET)
VBUS: C1.1, C5.1, C6.1, C7.1, C8.1, C15.1, J2.A4 (VBUS), J2.A9 (VBUS), J2.B4 (VBUS), J2.B9 (VBUS), U3.2 (EN), U3.3 (IN), U4.2 (VBUS), U6.2 (VIN2), U6.14 (VIN1)
VDD_A3P: C31.1, L3.1, U1.2 (VDDA3P3), U1.3 (VDDA3P3)

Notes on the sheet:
ESP32
IMU
Buttons
USB-C
Barometer
Decoupling Capacitors
Microphone
3V3 Buck
LED Buck
Light Sensor
Crystals
USB-C PD
Flash

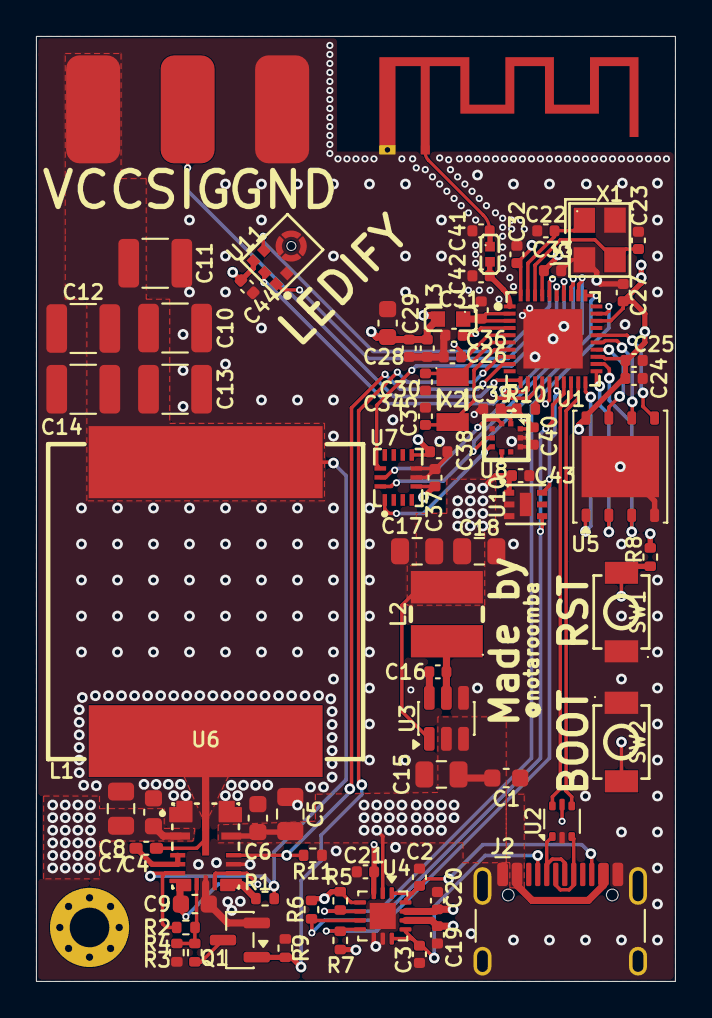
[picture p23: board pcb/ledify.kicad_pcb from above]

Board: 4 copper layers, 35.5 x 52.5 mm, 80 parts (0 on the bottom side), 48 nets.

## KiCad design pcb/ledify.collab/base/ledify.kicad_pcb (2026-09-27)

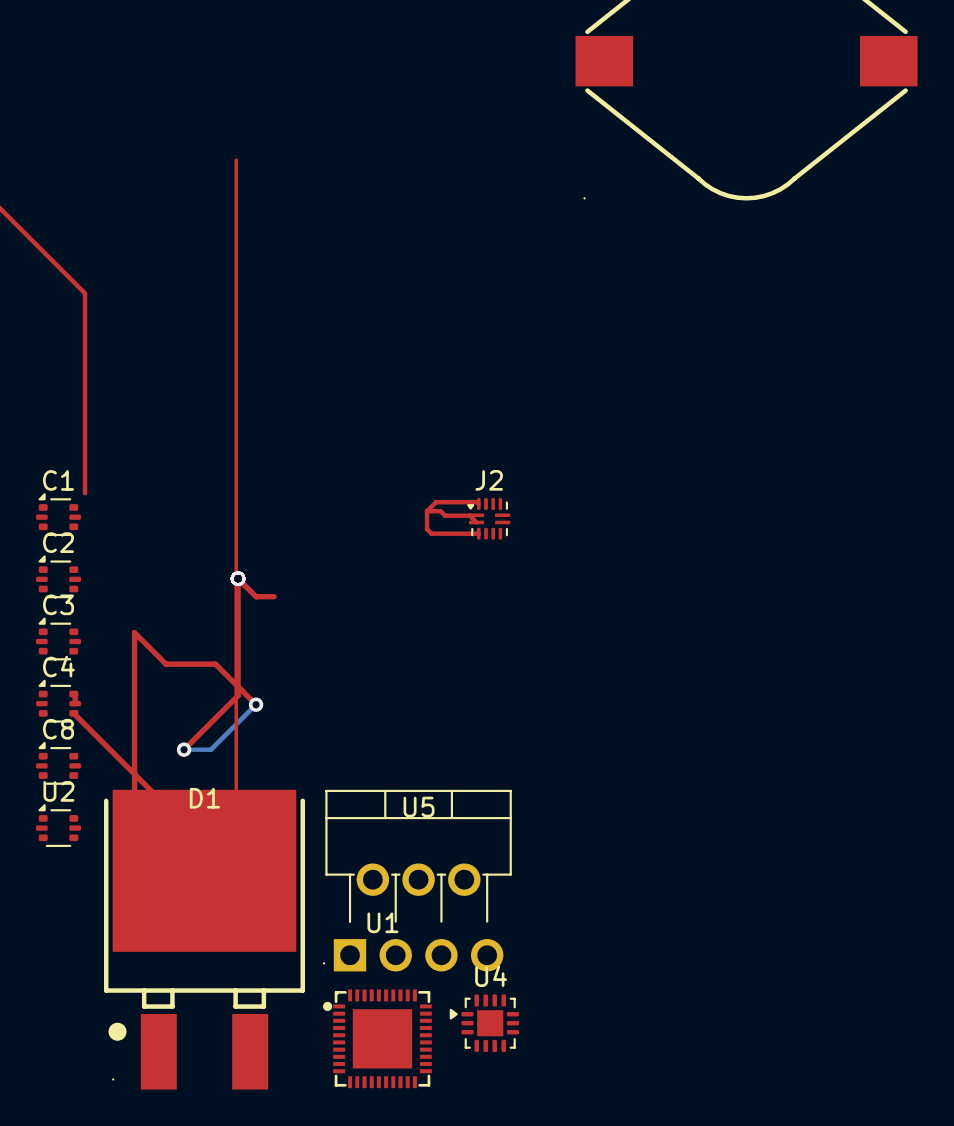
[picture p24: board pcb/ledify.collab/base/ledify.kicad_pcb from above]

Board: 2 copper layers, 12 parts (0 on the bottom side), 7 nets.

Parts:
C1: 4.7uF; SOT-666
C2, C3, C8: 400pF; SOT-666
C4: 470nF; SOT-666
D1: VS-6TQ045STRL-M3; TO-263AB_L10.0-W9.2-P5.08-LS15.4-BL
J2: USB_C_Receptacle_USB2.0_16P; Texas_X2QFN-12_1.6x1.6mm_P0.4mm
L1: DO5022P-103MLD; IND-SMD_L18.0-W15.2
U1: ESP32-C6_C5364646; QFN-40_L5.0-W5.0-P0.40-TL-EP3.3
U2: USBLC6-2P6; SOT-666
U4: FUSB302BMPX; WQFN-14-1EP_2.5x2.5mm_P0.5mm_EP1.45x1.45mm
U5: LM2678T-5.0/NOPB; TO-220-7-L10.5-W4.5-P1.27-BL

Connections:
/CC1: C3.1, U4.10 (CC1), U4.11 (CC1)
/CC2: C2.1, U4.1 (CC2), U4.14 (CC2)
GND: C1.2, C2.2, C3.2, C4.2, D1.3 (Anode), U1.41 (EP_41), U2.2 (GND), U4.8 (GND), U4.9 (GND), U4.15 (GND), U5.4 (GND)
unnamed: C8.2, D1.2 (cathode), L1.2 (2_2), U5.1 (Switch_output)
unnamed: U4.3 (VDD), U4.4 (VDD)
unnamed: C8.1, U5.3 (CB)
VBUS: C1.1, C4.1, U2.5 (VBUS), U4.2 (VBUS), U5.2 (Input)

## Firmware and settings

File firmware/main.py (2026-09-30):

# Ledify boilerplate: Bluetooth (Nordic UART service) -> addressable LEDs.
# Connect with any BLE UART app (nRF Connect, Bluefruit Connect) and send:
#   on | off | rgb R G B | volt 5 | volt 12
# Runs on MicroPython for ESP32-C6. On a laptop, `python3 main.py` runs the
# parser self-check instead.

try:
    import bluetooth
    import neopixel
    from machine import Pin
except ImportError:
    bluetooth = None

NUM_LEDS = 30  # length of your strip
MAX_LEVEL = 128  # brightness cap (0-255), lower it if the supply browns out

PIN_LED_DATA = 5  # LED_CON, the SIG pad
PIN_LED_ENABLE = 3  # LED_ENABLE, high = LED buck on
PIN_LED_12V = 2  # LED_SW_V, low = 5 V, high = 12 V


def parse(line):
    """'rgb 255 0 10' -> ('rgb', (255, 0, 10)). Returns None if invalid."""
    try:
        if isinstance(line, bytes):
            line = line.decode()
        parts = line.strip().lower().split()
        cmd, nums = parts[0], tuple(int(p) for p in parts[1:])
    except (ValueError, IndexError):  # UnicodeError is a ValueError
        return None
    if cmd in ("on", "off") and not nums:
        return cmd, nums
    if cmd == "rgb" and len(nums) == 3 and all(0 <= n <= 255 for n in nums):
        return cmd, nums
    if cmd == "volt" and nums in ((5,), (12,)):
        return cmd, nums
    return None


def run():
    enable = Pin(PIN_LED_ENABLE, Pin.OUT, value=0)
    sel_12v = Pin(PIN_LED_12V, Pin.OUT, value=0)
    strip = neopixel.NeoPixel(Pin(PIN_LED_DATA), NUM_LEDS)

    def fill(rgb):
        strip.fill(tuple(c * MAX_LEVEL // 255 for c in rgb))
        strip.write()

    def handle(line):
        parsed = parse(line)
        if parsed is None:
            return "err"
        cmd, nums = parsed
        if cmd == "on":
            enable.value(1)
        elif cmd == "off":
            fill((0, 0, 0))
            enable.value(0)
        elif cmd == "rgb":
            fill(nums)
        elif cmd == "volt":
            # never change the rail while the strip is powered, send "on" after
            enable.value(0)
            sel_12v.value(nums[0] == 12)
        return "ok"

    uart = bluetooth.UUID("6E400001-B5A3-F393-E0A9-E50E24DCCA9E")
    tx = (bluetooth.UUID("6E400003-B5A3-F393-E0A9-E50E24DCCA9E"), bluetooth.FLAG_NOTIFY)
    rx = (
        bluetooth.UUID("6E400002-B5A3-F393-E0A9-E50E24DCCA9E"),
        bluetooth.FLAG_WRITE | bluetooth.FLAG_WRITE_NO_RESPONSE,
    )
    name = b"Ledify"
    adv = bytes((2, 0x01, 0x06, len(name) + 1, 0x09)) + name

    ble = bluetooth.BLE()
    ble.active(True)
    ((tx_handle, rx_handle),) = ble.gatts_register_services(((uart, (tx, rx)),))
    connections = set()

    def irq(event, data):
        if event == 1:  # central connected
            connections.add(data[0])
        elif event == 2:  # central disconnected
            connections.discard(data[0])
            ble.gap_advertise(100_000, adv_data=adv)
        elif event == 3 and data[1] == rx_handle:  # write to RX
            reply = handle(ble.gatts_read(rx_handle))
            for conn in connections:
                ble.gatts_notify(conn, tx_handle, reply)

    ble.irq(irq)
    ble.gap_advertise(100_000, adv_data=adv)


def demo():
    assert parse("rgb 255 0 10") == ("rgb", (255, 0, 10))
    assert parse(b"ON\n") == ("on", ())
    assert parse("volt 12") == ("volt", (12,))
    assert parse("volt 9") is None
    assert parse("rgb 256 0 0") is None
    assert parse("rgb a b c") is None
    assert parse("on 1") is None
    assert parse("") is None
    assert parse(b"\xff\xfe") is None
    print("parser ok")


if bluetooth:
    run()
else:
    demo()

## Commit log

2026-09-08 add chips
    [ledify.kicad_pcb, ledify.kicad_sch]
2026-09-27 finished stuff
    [bom.csv, designators.csv, ledify.kicad_pcb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]
2026-09-27 finish prod
    [ledify.kicad_pcb, positions.csv]
2026-09-27 blender render
    [ledify.blend, ledify.kicad_pcb, ledify.kicad_sch]
2026-09-28 cool font thing
    [ledify.blend, ledify.kicad_pcb]
2026-09-28 fixes and done
    [bom.csv, designators.csv, ledify.blend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]
2026-09-29 fixes 2
    [ledify.blend]
2026-09-29 courtyard error
    [ledify.kicad_pcb]
2026-09-30 add light sensor and i2s mic, fix ground return paths, update journal
    [bom.csv, designators.csv, ledify.blend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]
2026-10-15 Firmware: ESP-IDF app with USB-PD, sensors, BLE, Wi-Fi + MQTT for Home Assistant, serial console and LED types
    Replaces the MicroPython boilerplate. Credentials and strip settings live in NVS (creds.example.csv documents the image), the app gets a 4 MB partition, and the README/journal cover the bring-up and the Mosquitto-on-Railway broker.
2026-10-15 Firmware: up to 1000 pixels, power-budget brightness cap, Home Assistant pixel slider and chip select
    count is 16-bit and resizes the RMT device, brightness is scaled to the PD contract (or 7.5 W without one) so long strips dim instead of browning out, the state JSON no longer embeds the SSID in quotes, and the LED type/count are exposed as MQTT discovery entities. Journal entry removed again; the journal stays hand-written.
2026-10-15 Docs: Home Assistant on Railway next to the broker
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2026-10-15 Firmware: sound level as approximate dB SPL with DC offset removed, pressure in kPa for Home Assistant
2026-10-15 Firmware: dynamic lighting, colour x brightness x overlay with sound, temperature and lux styles for Home Assistant
    Every frame is a colour source (solid, rainbow, temp, spectrum, meter) times a brightness
    (level, scaled by the lux curve with auto on and by the microphone with bright sound) times an
    overlay (none, vu, pulse), all drawn by leds_frame() so the power cap covers every style.
    mode NAME is a preset over the three and the Home Assistant effect list.
    The microphone runs in its own task: RMS with a saved gain and a peak follower, beat onsets,
    and bass/mid/treble from a 256-point fixed-point FFT (fft.c, checked by test/fft_test.c).
    The temp colour maps the barometer or a temperature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
2026-10-15 Firmware: real-time counters in the heartbeat (worst audio block time, dropped blocks, frame time, fps)
2026-10-15 Firmware: OTA over Wi-Fi with rollback (ota URL from BLE/console/MQTT), two app slots, firmware version in status, Wi-Fi modem sleep off
2026-10-15 Web control panel on Railway (MQTT over WebSockets, live spectrum, browser audio feed, presets, OTA button); firmware: 10 Hz live stream, audio feed, FastLED-style per-channel power model, 5 s teleme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
2026-10-15 Panel: redesigned controls (sliders with live values, hero power/brightness, hue slider, friendlier chips, advanced section)
2026-10-15 Firmware: take the most powerful PD offer and renegotiate for 12 V, optional power limit (off by default, draw and budget reported), real mic auto-gain with a noise gate, debounced NVS writes for sli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
2026-10-15 Panel: live sliders, power-limit toggle with draw warning, charger offers; new firmware image
2026-10-15 Firmware: volt 12 must be confirmed with 'yes' on every channel; panel asks first
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2026-10-15 Listen mode: the board streams 16 kHz PCM over MQTT and the panel plays it
2026-10-15 PD: after a reject use the source's 5 V rating, log skipped PDO types
2026-10-15 Firmware: four-boot log with PD results, pdmax ceiling, safe 5 V boot after two early deaths
2026-10-15 LEDs: resizing the strip no longer blanks it; only pixels past the new end go dark
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2026-10-15 Transitions, sleep and sunrise timers, schedules with SNTP, thermal limit, zones, BOOT button, local panel served by the board over mDNS and WebSocket, DDP and E1.31 pixel streams, OTA source pinning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
2026-10-15 README: rev 2 hardware plan (current sense, second data output, 5.2 V trim, injection pads, button, mic port)
2026-10-15 Album cover colours get their own gradient slot and 'cover' effect; the user's gradient persists in NVS; colombia built-in gradient; built-in gradients are always offered
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2026-10-15 Panel: colombia gradient uses pure red (the flag red reads pink on LEDs)
2026-10-15 Fix the audio feed being cut to 16 characters on the set topics (the board answered every packet with 'err, send help'); bad audio packets are dropped silently; panel toasts keep their colours, repea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
2026-11-10 Wi-Fi: up to 5 fallback networks (wifi2 SSID PASS|-, list, del, off, try); after 4 failed joins the board scans and joins the strongest saved network in range; open networks work. Fix the boot crash 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
2026-11-10 Sound styles eq, ripple, mirror, chroma, flow; sound styles at 60 fps; react setting; 16-band spectrum; browser simulator
    - fx.c: five whole-strip sound styles with instant attack and a release set by `react N` (1-100, saved)
    - mic.c/fft.c: FFT every 16 ms instead of 32, a 16-band log spectrum, beat counter and analysis timestamp
    (mic_snapshot), bands normalised against the loudest band's peak as well as full scale so mid/treble move
    at room levels
    - main.c: sound styles redraw every 16 ms (or as fast as the wire allows), the loop polls every 1 ms while a
    sound style is on; estimated sound-to-light delay in the 3 s log line and as "lat" in live; live carries "spec"
    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
2026-11-10 Panel: rewrite the interface around a live ring of the strip
    One screen instead of a long page of cards. The ring in the middle draws what the
    strip shows (same colour source, sound, overlay and zone pipeline as the board) and
    is the main control: drag around it for brightness, tap the middle for power, swipe
    across the middle to change effect. A dock opens one lens at a time beside it (a
    sheet on phones, a side panel on wide screens), and the ring changes with the lens:
    a hue wheel in Colour, draggable stops in Gradient, draggable zone edges in Zones.
    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
2026-11-10 creds.py: pull a board's saved settings into the local creds.csv and push them onto another board
2026-11-10 Wi-Fi: no panic when a disconnect arrives while the board is restarting after a saved setting (set_config failed in the stop state)
2026-11-10 Panel: brightness slider in the Colour, Gradient and Zones lenses, where the ring is busy picking hues, moving stops or zone edges
2026-11-10 Panel: listening to the board's mic no longer throws on audio packets that start at an odd byte offset (Int16Array needs an even offset, so copy first)
2026-11-10 Panel: rename a board from the Board lens; the picker shows each board's name instead of its MQTT id
    Uses the board's existing hostname setting (the name command), so it is saved on the board, shows the same in every browser and also becomes NAME.local. Typed spaces become dashes. Boards still on th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
2026-11-10 Panel: the board's answer to "status" (the whole state as JSON) is taken as state instead of shown as a toast on every load; long replies are cut and toasts wrap. The demo board now answers status th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
2026-11-10 Beat prediction: a tempo tracker (beat.c) lights beats on time instead of after they are heard
    - beat.c: onset strength (log spectral flux, kick bands weighted) every 16 ms, tempo by autocorrelation over 4 s
    every 0.5 s, phase by a comb, nudged by each heard onset (phase and a little tempo); predicts once periodic
    and 6 of the last 8 predicted beats landed, falls back after 3 empty beats
    - mic.c: predicted beats fire early by the render + wire time; heard onsets still drive beats until locked
    - main.c: a new beat is drawn at once instead of at the next 16 ms tick (heard beats ~10 ms to light instead of ~15);
    `predict 0|1` (saved, default 1); bpm and lock in status and live
    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
2026-11-10 Journal: stencil and first light, Oct 15 firmware, Nov 9 boards, Wi-Fi, sound modes and panel; same format as the keybytes journal (newest first, photos in assets/journal)
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2026-11-10 Journal: split the bring-up into 10/13 (stencil, paste, hotplate; boards shorted) and the later short fix and first light
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2026-11-10 Mic audio only goes back the way listen came; board WebSocket only for its own page
    A listen over MQTT streams to the broker, one from the board's WebSocket stays on the LAN.
    The WebSocket refuses other Hosts and Origins (cross-site pages, DNS rebinding) and only
    takes commands from sockets that passed that check.
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2026-11-10 Setup window: hold the button 3 s to link a browser and change Wi-Fi or broker
    wifi, wifi2, mqtt, otabase (and ota with no otabase) now need the USB console or the
    2-minute window. The window's one-time code goes to ledify/<id>/pair for the panel server
    and to the board's own page and Bluetooth (pair command), never to MQTT replies.
2026-11-10 Panel accounts: per-board broker logins, links in person, share links
    A small Node server replaces Caddy. With OWNER_PASS and the broker admin set it gives each
    board and each browser its own Mosquitto dynamic security account, links a browser to a
    board from the board's setup code or a single-use share link, remembers browsers with a
    cookie and logs the owner in. Without them it serves the panel exactly as before.
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2026-11-10 Height: settle the barometer before taking height 0
    The first readings after boot came from the BMP581 before its new 32x/20 Hz
    configuration had settled, and one of them became the reference, leaving a
    steady offset (+30 cm seen on the board). Now the first second of readings is
    skipped and the next half second averaged; height is zeroed again when the
    board first calibrates, and picking the height style re-zeroes it even when
    it is already showing.
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2026-11-10 Height: hold it while the board rests, let height 0 follow the pressure
    On the board the pressure crept ~4.6 Pa over 3 minutes after a restart
    (about -38 cm) while it sat still and cooled 1.3 degrees. While the IMU
    sees no movement, the barometer's change is now absorbed into the
    reference (over ~2 s) instead of the height. Also fixes the OSR_EFF log
    label: pressure is at 32x, temperature at 2x, as configured.
2026-11-10 Height hold: its own debounced movement test, rest detector on smoothed data
    On the board the rest flag dropped for single samples every ~30 s with
    nobody near it, and each drop let 1-2 cm of pressure creep into the height.
    - the rest detector's per-sample test now uses gyro and |a| smoothed over
    50 ms, and a still second is judged by standard deviation, not range
    - the height hold no longer uses the rest flag: it needs 1 s with the
    change in acceleration under 0.012 g and turning under 3 deg/s (both
    smoothed), so a sensor offset, noise or a tap on the desk doesn't count;
    the first 3 s of a hold still let the barometer finish settling a move
    - motion JSON/console show the hold
2026-11-10 Link boards over Bluetooth only: the board's page no longer gives out the setup code
    pair now answers only over USB and Bluetooth, and the board stops pushing the code to its
    WebSocket. The panel drops the local link banner; the first-visit screen links over
    Bluetooth from the hosted panel.
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2026-11-10 Panel server: only reset a broker password when it changed
    setClientPassword drops that user's connections, so every panel restart kicked every
    board on the shared login. Keep a hash of the last password set and skip it when equal.
2026-11-10 Height: settle exactly at 0 after boot
    On the board height held at 2.5 cm after boot: the half-second reference
    sat off on barometer noise. The first rest after boot (within 15 s, with
    nothing lifted) now sets height 0 again, and the first hold after
    calibration counts as a hold break with nothing lifted.
2026-11-10 Height: fast barometer crossover while moving, freeze on a 2 s average
    On the board's lift test height overshot the barometer by ~11 cm with vz
    stuck at 0.4 m/s while held up: the accelerometer's vertical offset shifts
    with how the board is turned, and the 0.8 rad/s crossover let ~0.03 g of
    it through. While moving the crossover is now 2 rad/s (host test with that
    offset: 13.2 cm -> 3.2 cm), 0.8 rad/s again a quarter second after it
    stops, and a rest freezes the height on a 2 s barometer average.
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2026-11-10 Panel: Matrix lens to play video, pictures, a screen, the camera or text
    Sets up the matrix (size, first pixel, rows or columns, zig-zag, with a
    wiring diagram and test pattern) and streams frames scaled in the browser
    with brightness and gamma. Frames go over the board's WebSocket on its own
    page, or the broker on the hosted panel, dropping frames rather than queuing.
    Linked browsers may publish frame/set; panels no longer subscribe to '#'.
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2026-11-10 Fused sound + motion styles: aurora, fire, bounce, comet
    Four whole-strip styles that listen to the mic and feel the IMU at once:
    aurora (curtains that swell with the room and drift downhill), fire
    (flames rise from whichever end is down, fed by sound and shaking),
    bounce (balls under real gravity, kicked up by beats and knocks) and
    comet (two comets crossing in the middle on every beat at the locked
    tempo). fxpal 1 draws them in the user's gradient. mic_snap_t now
    carries bpm and lock. Host tests in test/fx_test.c.
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
